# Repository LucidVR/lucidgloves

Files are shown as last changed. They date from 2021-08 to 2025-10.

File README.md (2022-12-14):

LucidGloves

# LucidGloves - Firmware and 3D Printer Files
This repo contains the arduino firmware as well as the STL files for Prototypes 3 through 4 of the LucidVR glove. This is a finger tracking glove that allows you to use your hands in VR. Follow along with Lucas_VRTech's developments on his Tiktok page:
https://www.tiktok.com/@lucas_vrtech

# Building your own gloves
**Start here at the wiki! https://github.com/LucidVR/lucidgloves/wiki**

# Support
Join the LucidVR discord server for assistance:
https://discord.gg/lucidvr

# Firmware
Open the firmware files located in the firmware/lucidgloves-firmware folder.
By default the firmware is configured for an arduino nano using serial.
To configure the firmware, change the defines in the lucidgloves-firmware.ino file.

**Configuration instructions are here: [Configuration Instructions](https://github.com/LucidVR/lucidgloves/wiki/Firmware-Setup-and-Customization-Tutorial).**\
**Firmware Troubleshooting Guide is here: [Firmware Troubleshooting Guide](https://github.com/LucidVR/lucidgloves/wiki/Firmware-Troubleshooting-Guide).** 

## Tested boards:
* Arduino Nano
* ESP-WROOM-32

## Supported Communication Methods:
* USB Serial
* Bluetooth Serial (On ESP32 boards)
* BLE (Soon, not up yet)

# Hardware
STL files for 3D printing are located in the hardware folder. 
*Prototype 4 models are currently experimental.*

The assembly **for each hand** is as follows:

For Prototypes 3 and 3.1 - 
* Spool (5x)
* Tensioner (5x)
* Cover (5x)
* Holder (5x)
* GuideRing(Will need to be resized) OR GuideNode(3.1) (2+ per finger, 1+ for thumb)
* EndCap (1x per finger, will need to be resized to fit) 

For Prototypes 4 and 4.1 - 
* HapticSpool (5x)
* Tensioner_GreenPot (5x) OR Tensioner_WLPot (5x)
* SpoolCover (5x)
* RigidMount (1x) (Left or right hand)
* WLPotSlideHolder OR WLPotElasticHolder OR GreenPotSlideHolder (5x)
* Quest2_MountSlider OR Vive3.0_MountSlider (1x)
* GuideRing (Proto 3) (Will need to be resized) OR GuideNode (Proto 3.1) (2+ per finger, 1+ for thumb)
* EndCap (Proto 3) (1x per finger, will need to be resized to fit)

Guide for printing parts: [Printing guide](https://github.com/LucidVR/lucidgloves/wiki/Parts-Printing-Guides)

**Required parts for each hand: [Parts Lists](https://github.com/LucidVR/lucidgloves/wiki/Parts-Lists)**  
Optional:  
* Joysticks for locomotion 
  - Will be making a DIY treadmill eventually as well for those who would prefer that  
* Buttons (Most can be replaced with gestures) (One is required for autocalibration)

More information will be available on the [LucidVR site](http://lucidvrtech.com/) very soon.  
*  [Prototype 3/3.1 Building Tutorial](https://youtu.be/Qj4hqRKiy8g)
*  [Prototype 4/4.1 Building Tutorial](https://youtu.be/2yF-SJcg3zQ)

# SteamVR Compatibility (OpenGloves)
This project uses the OpenGloves OpenVR driver for compatibility with SteamVR, which is downloadable on Steam:  
https://store.steampowered.com/app/1574050/OpenGloves/

Source code available on GitHub:  
https://github.com/LucidVR/opengloves-driver

# Other Languages
**[English](https://github.com/LucidVR/lucidgloves/blob/main/README.md) | [简体中文](https://github.com/LucidVR/lucidgloves/blob/main/Readme_Languages/README_CN.md)**

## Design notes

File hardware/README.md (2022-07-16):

# lucidgloves-hardware

Here are the 3D models for your printed glove parts.
The x.1 versions have slight tweaks over their counterparts to make them more easily printable and durable, so prefer those when available.
If you are on the fence between having haptics or not, you can print the Prototype v4 without servos and add them later.

Check the [printing guides](https://github.com/LucidVR/lucidgloves/wiki/Parts-Printing-Guide) to know how many you need to print and how.

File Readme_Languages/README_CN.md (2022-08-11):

LucidGloves

# lucid手套- 固件与3D打印文件
此Repo含有lucid手套的原型机V3到V4的arduino固件以及3D打印所需要的STL文件。LucidGloves是DIY触觉反馈手指追踪手套，如果配合LucidVR使用，可以在大部分支持Valve Index手柄支持的游戏。我们的宗旨是用最少的钱，得到最大的体验。原作者Lucas_VRTech会在他的抖音账号里更新此项目的最新进展, 请关注https://www.tiktok.com/@lucas_vrtech 。

# 支持此项目
欢迎计入LucidVR的discord服务器，更多详细问题以及内容可以在LucidVR的官方discord讨论:
https://discord.gg/lucidvr

# 固件
固件文件在firmware/lucidgloves-firmware文件夹.
此固件默认使用和配置arduino nano以及它的USB通讯端口。如果使用USB通讯端口，您需要使用相应的数据项与设备相连。
如果您想配置此固件，请在lucidgloves-firmware.ino文件做出相应的改变。

**详细的配置方法：请点击此处进入配置教程 -> [配置教程传送门](https://github.com/LucidVR/lucidgloves-hardware/wiki/Firmware-V2-Customization).**\
**固件问题的故障排除教程：-> [固件故障排除教程](https://github.com/LucidVR/lucidgloves/wiki/Firmware-Troubleshooting-Guide).** 

## 已测试过的主板:
	* Arduino Nano
	* ESP-WROOM-32

## 现已支持的通讯方法:
	* USB Serial
	* Bluetooth Serial (可以在 ESP32 boards实现，详情请看教程。)
	* BLE (敬请期待)

# 硬件
3D打印所需要的STL文件在hardware文件夹。
*关于原型机V4:目前还在测试阶段*

以下是针对**单个手套**需要打印以下材料：

原型机V3/V3.1：
* Spool (5x) | 卷轴
* Tensioner (5x) | 卷轴张紧器
* Cover (5x) | 卷轴保护外圈
* Holder (5x) | 卷轴固定器
* GuideRing(Will need to be resized) OR GuideNode(3.1) (2+ per finger, 1+ for thumb) | 导环
* EndCap (1x per finger, will need to be resized to fit)  | 手指套

原型机V4/V4.1：
* HapticSpool (5x) | 触觉反馈卷轴
* Tensioner_GreenPot (5x) OR Tensioner_WLPot (5x) | 触觉反馈卷轴张紧器，根据您的电位器型号选择
* SpoolCover (5x) | 卷轴保护外圈
* RigidMount (2x) (One for each hand, make sure to flip for other hand) | 固定装置
* WLPotSlideHolder OR WLPotElasticHolder OR GreenPotSlideHolder (5x) | 卷轴滑轨固定器
* Quest2_MountSlider OR Vive3.0_MountSlider (2x) | Quest2手柄固定器
* GuideRing (Proto 3) (Will need to be resized) OR GuideNode (Proto 3.1) (2+ per finger, 1+ for thumb) | 导环
* EndCap (Proto 3) (1x per finger, will need to be resized to fit) | 手指套

3D打印教程: [打印教程传送门](https://github.com/LucidVR/lucidgloves-hardware/wiki/Parts-Printing-Guides)

**需要购买的材料: [所需材料传送门](https://github.com/LucidVR/lucidgloves/wiki/Parts-Lists)**  
可选配置:  
* 遥感：可以控制人物在游戏里的运动
  - 此项目的最终计划是加入VR跑步机
* 按钮 (几乎所有按钮都可用手势替代) (至少需要一个来用作自动校准)

想要更多信息和情报？请关注[LucidVR官方网站](http://lucidvrtech.com/). 
*  [原型机V3/V3.1制作教程](https://youtu.be/Qj4hqRKiy8g)
*  原型机V4的教程会很快跟进的。

# SteamVR兼容性(OpenGloves)
此项会用到OpenVR驱动程序去兼容SteamVR, 您可以到Steam下载:  
https://store.steampowered.com/app/1574050/OpenGloves/

GitHub上已公布的源代码:  
https://github.com/LucidVR/opengloves-driver

# Other Languages
**[English](https://github.com/LucidVR/lucidgloves/blob/main/README.md) | [简体中文](https://github.com/LucidVR/lucidgloves/blob/main/Readme_Languages/README_CN.md)**

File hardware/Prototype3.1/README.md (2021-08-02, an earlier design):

# LucidGloves Hardware Prototype 3.1

See [readme.md](readme.md) for the master readme of this repository.

This folder contains the STl files for Prototype 3.1 of the LucidGloves.
Please see [Printing guide](https://github.com/LucidVR/lucidgloves-hardware/wiki/Parts-Printing-Guide) for printing instructions.

Here is a list of modified versions of Prototype 3.1:  
* Feel free to pull request a repo link to your modded version.
  - Should follow the structure of "Mod name - mod creator - link to mod"

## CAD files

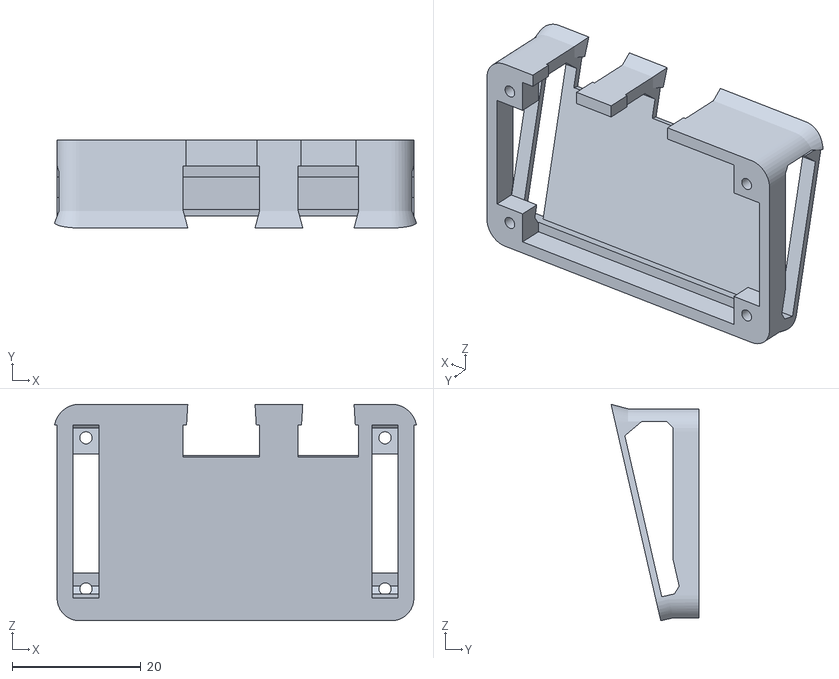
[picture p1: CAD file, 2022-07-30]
hardware/MicrocontrollerMounts/ESP32_Wroom_Holder_Desoldered_JST.STL
56.3 x 13.7 x 33.7

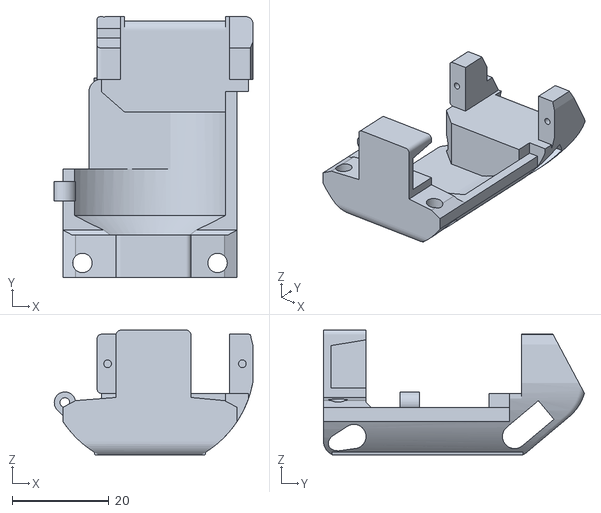
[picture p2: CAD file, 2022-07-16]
hardware/Prototype4.1/GreenPotElasticHolder_Proto4.1.STL
41.0 x 53.9 x 25.8

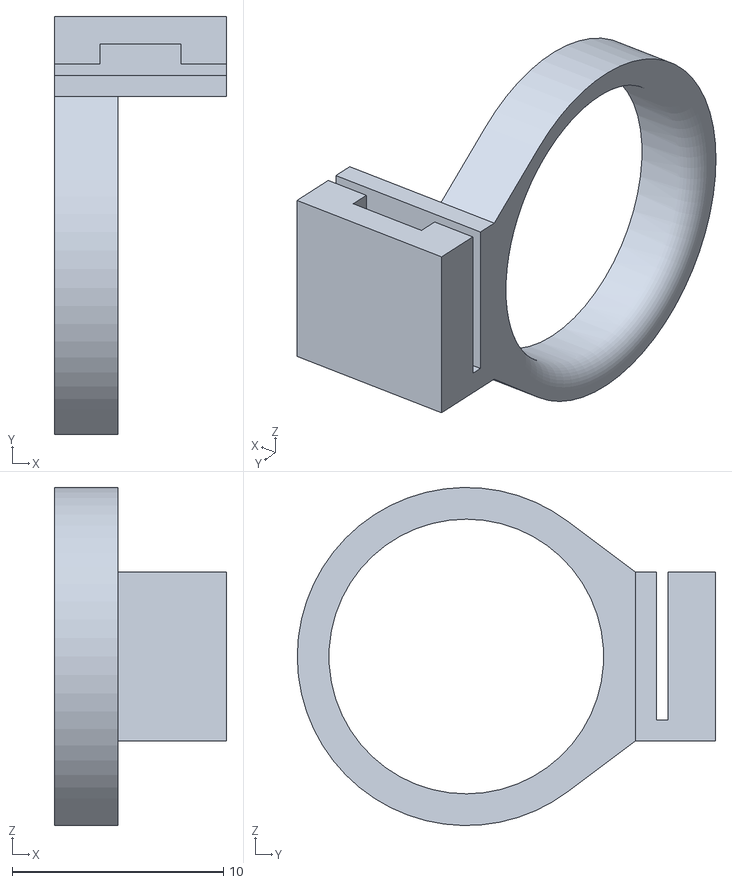
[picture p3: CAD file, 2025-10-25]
hardware/Prototype5_BETA/EndRings/EndRing_v1.2_13mm.STL
8.15 x 19.8 x 16.0

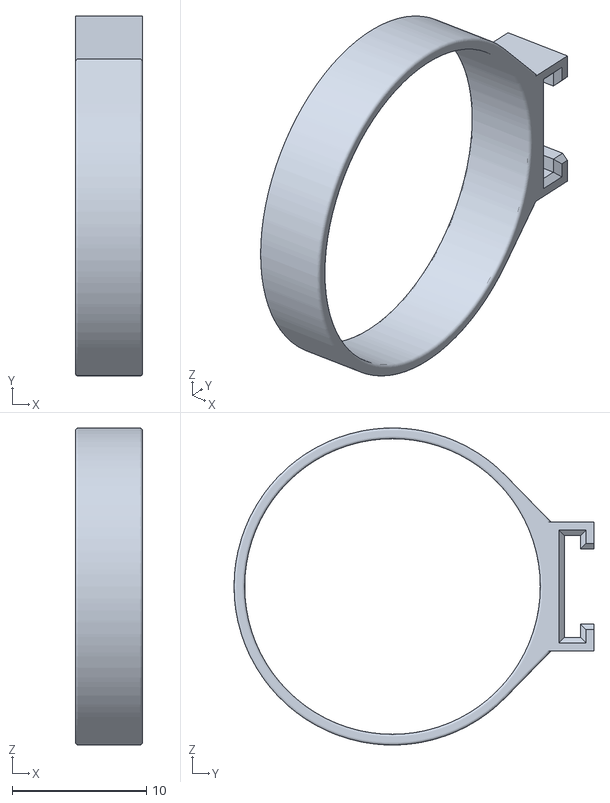
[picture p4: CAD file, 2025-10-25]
hardware/Prototype5_BETA/GuideRings/GuideRing_v1.2_22mm.STL
5.00 x 26.8 x 23.6

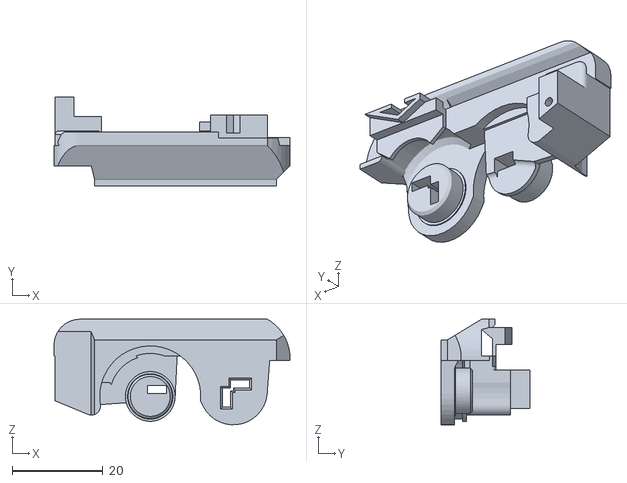
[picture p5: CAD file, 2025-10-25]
hardware/Prototype5_BETA/SensorHousing_v5.9.STL
52.1 x 19.7 x 23.3

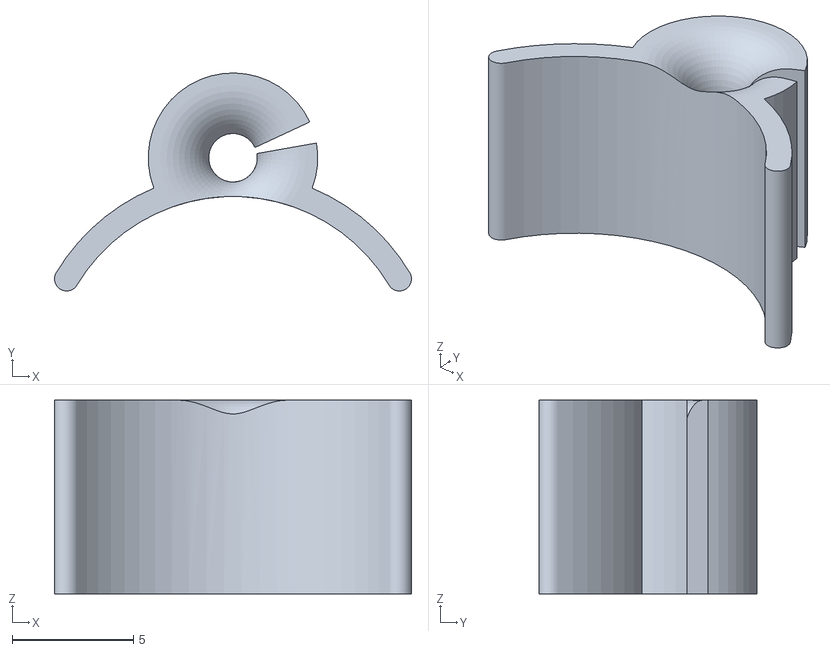
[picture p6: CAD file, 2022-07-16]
hardware/Prototype4.1/GuideNode_upgraded.STL
14.7 x 9.00 x 8.00

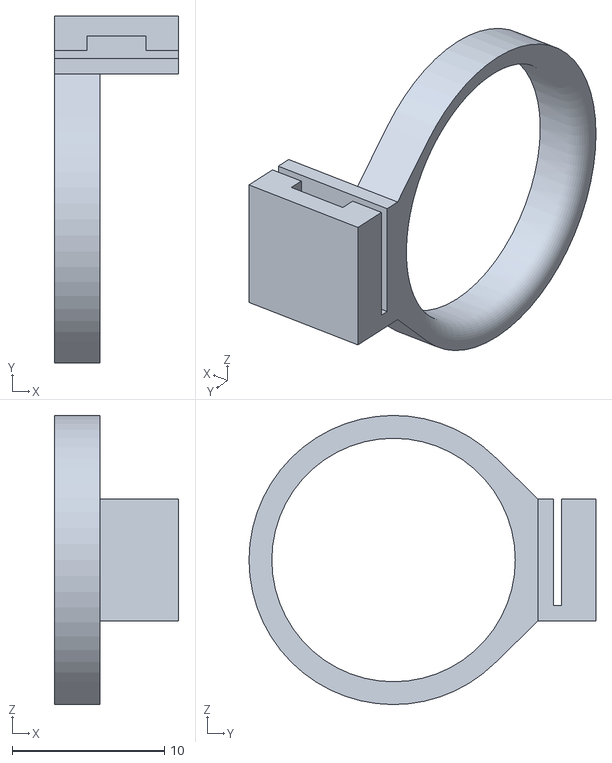
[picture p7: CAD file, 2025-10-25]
hardware/Prototype5_BETA/EndRings/EndRing_v1.2_16mm.STL
8.15 x 22.8 x 19.0

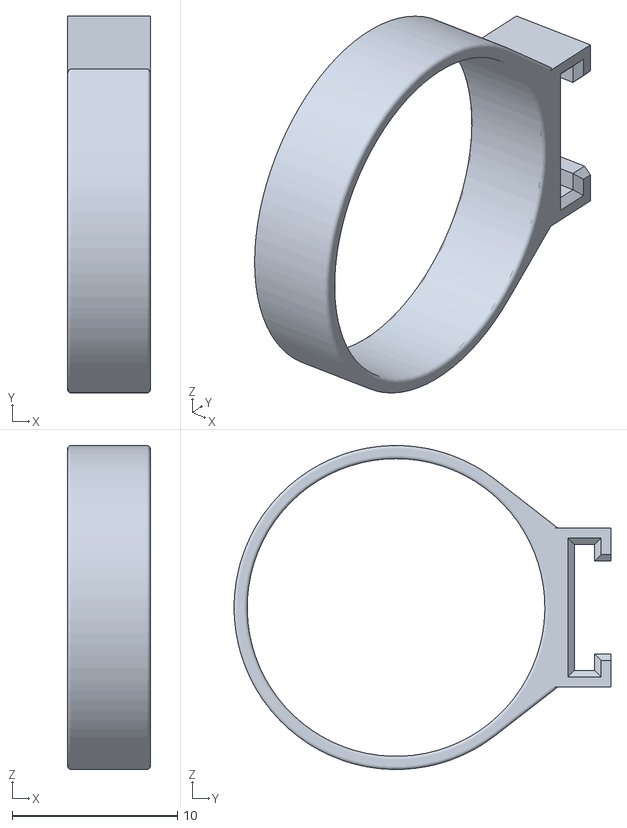
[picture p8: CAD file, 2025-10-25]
hardware/Prototype5_BETA/GuideRings/GuideRing_v1.2_18mm.STL
5.00 x 22.8 x 19.6

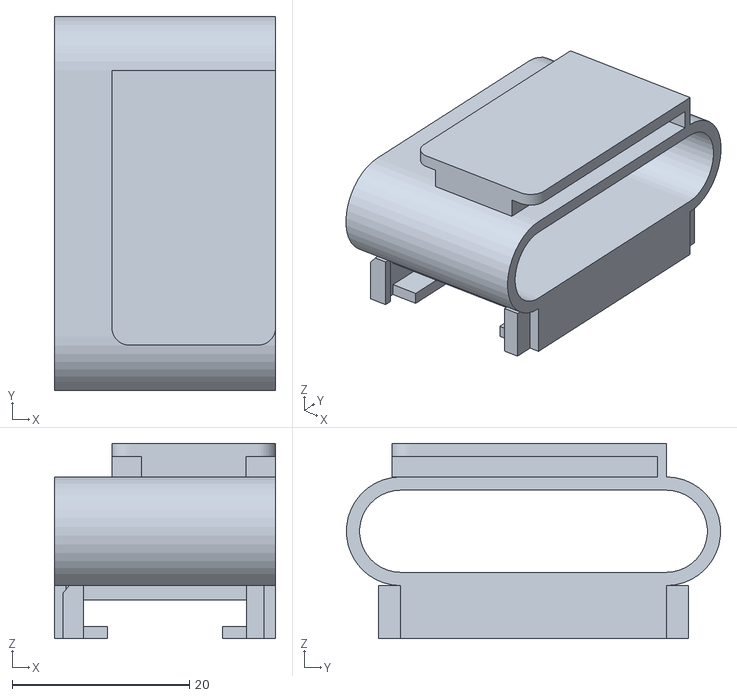
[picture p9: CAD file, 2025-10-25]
hardware/Prototype5_BETA/MountSpacer_V1.STL
25.0 x 42.2 x 22.1

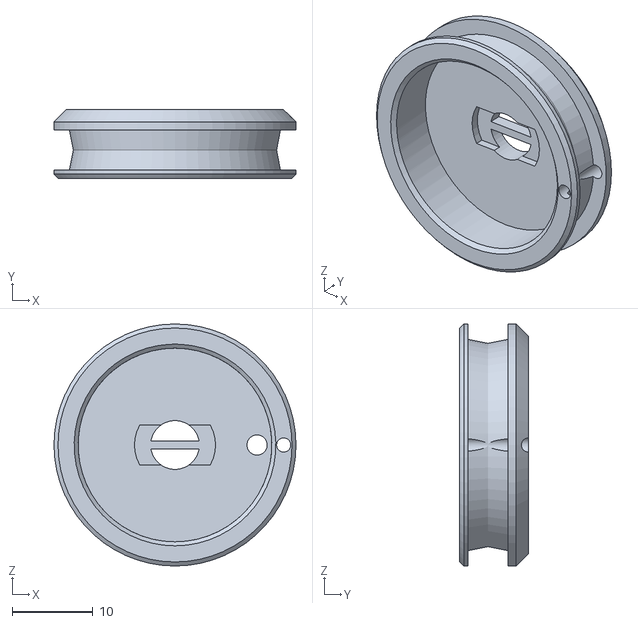
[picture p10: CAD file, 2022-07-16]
hardware/Prototype4.1/HapticSpool_Proto4.1.STL
30.0 x 8.50 x 30.0

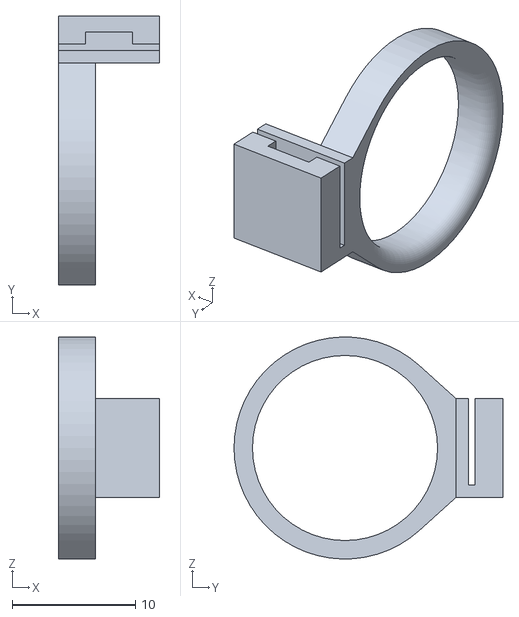
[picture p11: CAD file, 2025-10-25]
hardware/Prototype5_BETA/EndRings/EndRing_v1.2_15mm.STL
8.15 x 21.8 x 18.0

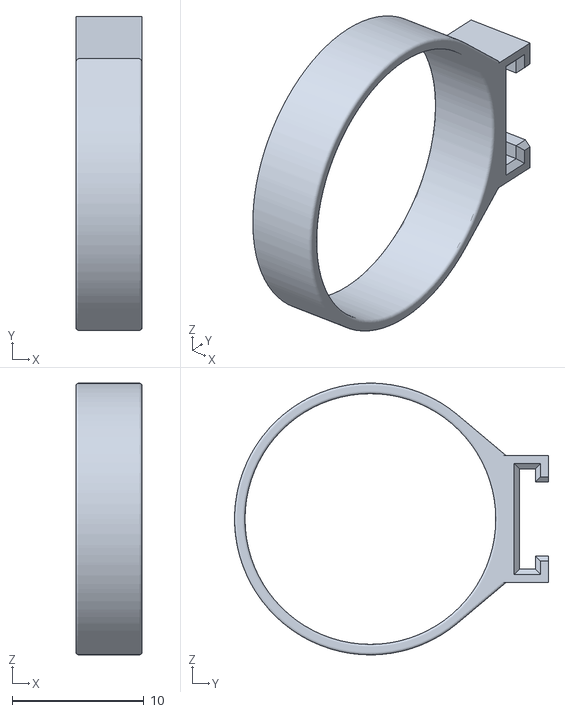
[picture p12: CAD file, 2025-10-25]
hardware/Prototype5_BETA/GuideRings/GuideRing_v1.2_19mm.STL
5.00 x 23.8 x 20.6

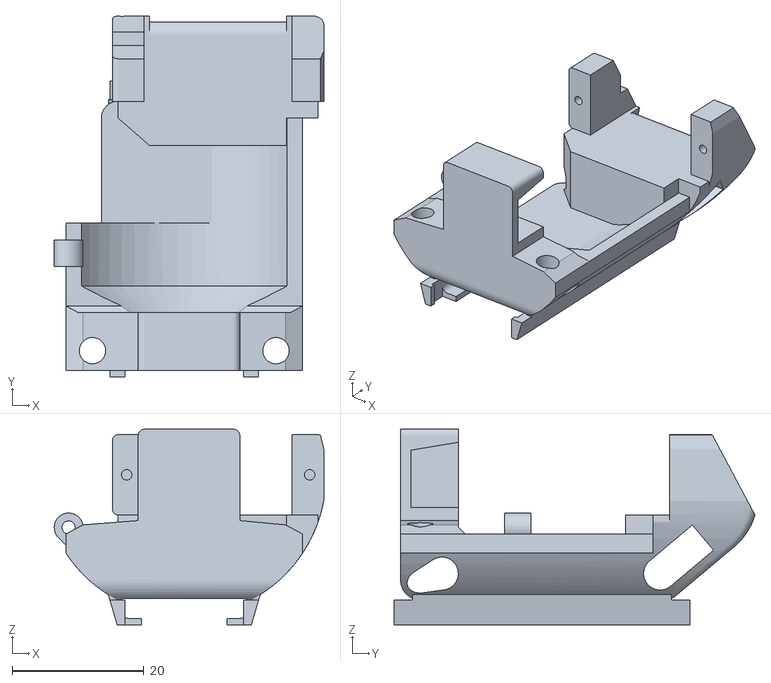
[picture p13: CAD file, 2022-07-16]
hardware/Prototype4.1/GreenPotSildeHolder_Proto4.1.STL
41.0 x 54.9 x 29.8

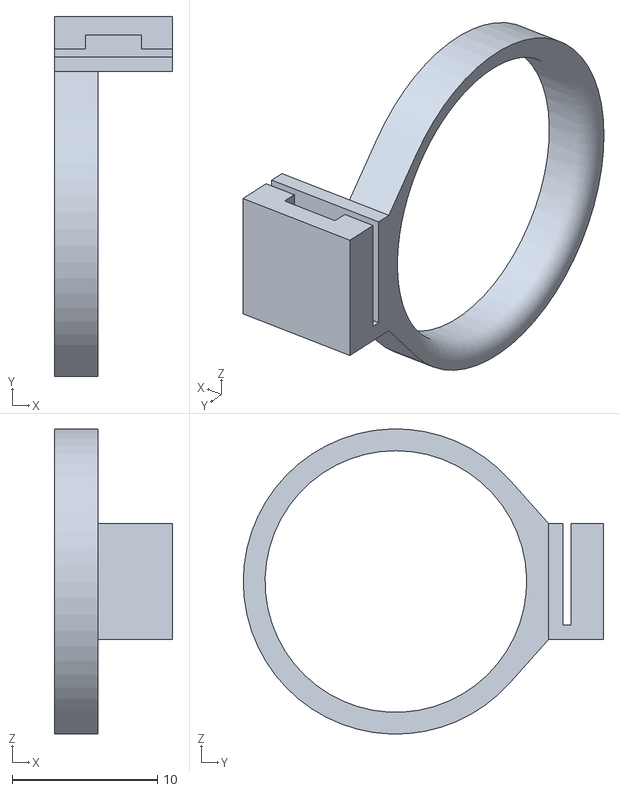
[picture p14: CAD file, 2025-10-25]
hardware/Prototype5_BETA/EndRings/EndRing_v1.2_18mm.STL
8.15 x 24.8 x 21.0

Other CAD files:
hardware/Prototype5_BETA/GuideRings/GuideRing_v1.2_17mm.STL
hardware/Prototype5_BETA/RigidMount_Splay_v4.STL
hardware/Prototype4.1/WLPotSlideHolder_Proto4.1.STL
hardware/Prototype5_BETA/GuideRings/GuideRing_v1.2_15mm.STL
hardware/Prototype3.1/Prot3.1R2_EasySpool.STL
hardware/Prototype3.1/Prot3.1R2_SpoolCover.STL
hardware/Prototype3.1/Prot3.1R2_SpoolCover_Taller.STL
hardware/Prototype3.1/Prot3.1_GuideNode.STL
hardware/Prototype3.1/Prot3.1_Holder.stl
hardware/Prototype3.1/Prot3.1_Wirecover_PublicBeta.STL
hardware/Prototype3/Prot3_Cover.STL
hardware/Prototype3/Prot3_GuideRing.STL
hardware/Prototype3/Prot3_Holder.STL
hardware/Prototype3/Prot3_Spool.STL
hardware/Prototype3/Prot3_Tensioner.STL
hardware/Prototype4.1/Vive3.0_MountSlider_v1.2.STL
hardware/Prototype4.1/WLPotElasticHolder_Proto4.1.STL
hardware/Prototype4/GreenPotElasticHolder.stl
hardware/Prototype4/GreenPotSlideHolder.STL
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

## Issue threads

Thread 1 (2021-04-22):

Assembly Guide Prototype 3

Lobotuerk, 2021-04-22:
Do you have a video or a guide to assembly prototype 3? The videos on your channel show one of the older ones, and I printed the parts for the 3.1 and have no idea how to assembly it. Thanks in advance

lucas-vrtech, 2021-04-24:
I am going to be posting a video tutorial on youtube soon.

CameronKlinge, 2021-05-02:
i need help with wiring, so I see that on the wiring demonstration it shows how to wire to the AO A1 and so on but the other 2 pins on the petameter I don't get how to wire those. btw im wiring it without a breadboard.

lucas-vrtech, 2021-05-02:
@CameronKlinge The other two pins correspond to GND and 5V. It needs to be split from the Arduino so that each potentiometer can get GND and 5V. (Or 3V3 if using an ESP32)

This guide may help:
https://www.arduino.cc/en/tutorial/potentiometer

CameronKlinge, 2021-05-02:
@lucas-vrtech Ok that makes more sense thank you so much!

danwillm, 2021-06-04:
Going to close this now that the tutorial is out, but please do feel free to re-open if you need more clarification.

Lobotuerk, 2021-06-04:
Thank you @danwillm , Awesome work

Closed 2021-06-04.

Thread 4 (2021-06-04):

Plans to support Wifi communication?

Nitwel, 2021-06-04:
Are there any plans on supporting this using websockets or something? Or are there reasons not to go this road like latency or complexity?

LittleNyanCat, 2021-11-14:
The main reason WI-FI hasn't been implemented yet is that using it on the ESP32 disables ADC2, leaving us with only 6 pins available for analog input, making tracking all fingers while having a joystick impossible without extra hardware.

You're free to implement it and contribute if you wish, but for now we don't have enough reasons to do so ourselves

minystreem, 2022-01-06:
I could try to program this, otherwise I can close this issue.

danwillm, 2022-01-06:
@minystreem
You are very welcome to implement this feature, there's been a number of people who have suggested it.

minystreem, 2022-01-06:
Ok I will start on it, I may have to make changes to Lucid-ui

danwillm, 2022-01-06:
You shouldn't have to do much on the UI, it automatically loads all the settings in `default.vrsettings` file found in the driver. Though you can add your own custom titles and descriptions to the labels and tooltips.

The majority of the work will be on the driver and firmware. Let me know if you have problems with any of that.

minystreem, 2022-01-06:
Yea I meant the driver sry. I am having trouble finding a good library

danwillm, 2022-01-06:
I recommend ASIO
https://think-async.com/Asio/

minystreem, 2022-01-06:
does that work for the esp32

danwillm, 2022-01-06:
Sorry, linked the wrong library https://github.com/zaphoyd/websocketpp (this one is the one @Nitwel was originally using but I don't think he finished his implementation)

minystreem, 2022-01-06:
So that's the library I should use for the client side AND the sever side

danwillm, 2022-01-06:
Just driver, I'm sure there's other arduino libraries for wifi.

minystreem, 2022-01-06:
Ok, I will try to find one, the WiFi library is outdated so I might have to find a different one

LittleNyanCat, 2022-01-06:
For the Esp side I've used this one for websockets in one of my projects before:
https://github.com/me-no-dev/ESPAsyncWebServer

minystreem, 2022-01-06:
Ok thx

minystreem, 2022-01-13:
@LittleNyanCat would you like to help do the driver side of things? my c++ is not very good, I got the esp side kinda working, I'm still working on it I got a bit busy. If your could help that would be nice but if not that's fine.

LittleNyanCat, 2022-01-13:
Uhh, the Arduino side stuff is also C++ though?

I'd help right now if I didn't find setting stuff up to build the driver to be such a chore

I won't be touching any driver related stuff until my gyros arrive in about a month, when that happens maybe I'll take a look at it

minystreem, 2022-01-13:
Yea building stuff is a chore for too, I'll finish the esp side

Veillax135, 2022-01-13:
Sorry, not available right now. I would if I had the time.

-Veillax135

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

CaelanTheCoder, 2022-08-16:
There's like 66 forks of this project; pretty sure at least one person has implemented WIFI communication.

minystreem, 2022-12-11:
no, I kinda abanonded it becuse I dont get the point. most forks dont have any changes

minystreem, 2022-12-11:
Wifi communicaion is hard, you try doing it

AthemiS13, 2024-12-10:
> Wifi communicaion is hard, you try doing it

Hey, have you managed to get it working? I want to do something simmilar

ElectricTurtle32, 2024-12-10:
I got the aurdino side working, but not the Pc side, I would need to dig up
the code though lol

On Tue, Dec 10, 2024, 3:44 AM Jakub Chmelař ***@***.***>
wrote:

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

AthemiS13, 2024-12-10:
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

Could you send me your discord or something please so i can contact you privately?

ElectricTurtle32, 2024-12-16:
I don't think I have the code anymore unfortunately, I am very sorry. I
wish you luck on your project though!

On Tue, Dec 10, 2024 at 8:31 AM Jakub Chmelař ***@***.***>
wrote:

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

JohnRThomas, 2024-12-23:
@AthemiS13 The driver needs to be modified, but this is the start of serial over wifi that you can rip from my fork if you want to try it: https://github.com/JohnRThomas/OpenGloves-Firmware/blob/main/open-gloves/SerialWIFICommunication.hpp

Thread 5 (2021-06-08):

Suggestions for the 3D models.

Nitwel, 2021-06-08:
I'm currently printing the parts for the glove and noticed some minor problems with the 3d models that could be improved upon.

1. The tensioner has this small corner arround it which my prusa mini couldn't handle even on 0.10mm layer height so the casing wouldn't hold. I added a bigger corner to hold on to which was much easier to print even on 0.25mm layer height. So if you'd like you could add this to the tensioner.
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

2. The overhang on the spool hoder could cause trouble when printing so adding a soother edge here could improve the prints:
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

Other than that the 3D Models are really well designed and I'm really excited to test the glove out!
Thank you so much for comming up with this idea and making it a reality. ❤️

lucas-vrtech, 2021-06-19:
Yeah, I have some printability improvements coming up in prototype 4 soon. I'll make some changes to the snap ridge you mentioned, but unfortunately adding a chamfer to the spool like in your second image may be problematic as in my testing it sometimes guides the string off of the spool requiring you to take it apart and fix

Closed 2021-06-19.

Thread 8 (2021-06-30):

No home button mapping in firmware

Watermelon4man, 2021-06-30:
Add a home button define pin in the firmware as it is missing.

lucas-vrtech, 2021-06-30:
Good idea, I can add that in. It is also missing from the driver so I'll have to add it there as well.

lucas-vrtech, 2021-08-03:
I've added a menu button to the firmware and driver. Will be released with OpenGloves driver v0.4 :)

Closed 2021-08-03.

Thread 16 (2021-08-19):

Add documentation for adding required ESP32 libraries

lucas-vrtech, 2021-08-19:
This is a pretty quick first issue if someone wants to take it,
Currently in order to use the firmware with ESP32, one needs to get the ESP32 libraries from the Arduino IDE package manager,
And in order to use the servos for force feedback, one needs to get the ESP32servo library

Closed 2021-09-01.

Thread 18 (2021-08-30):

OBJ or  similar file type for the 3d parts?

MJ26gaming, 2021-08-30:
The STLs work fine for 3d printing, but having OBJs or STEPs for them so that way we can edit and customize them in CAD software would be nice

Bossbam, 2021-09-02:
I know it's not the best solution, but if you just download blender you can really quickly import the file as an STL and then export it as an OBJ

lucas-vrtech, 2021-09-04:
Currently, I am not releasing the step files for the entire glove itself, but will be probably releasing step files for the modular controller mount system soon. This may change in the future.

Closed 2021-09-04.

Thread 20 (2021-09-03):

Inseam on spool too small

Rat-Boi-Bop, 2021-09-03:
I am a dumb person and would like help. The inseam on the spool stl file isn't showing up on the layer view, apparently it is so small my printer can't see it and so it just skips it. You can see how this is an issue. Please advise.

Zach710032, 2021-09-03:
same probelm as above^ adding z layer fixed it.

lucas-vrtech, 2021-09-04:
I will be throwing up some new STL files with release proto 4.0.1 which will fix this issue. Thank you for pointing it out. This is actually a problem carried from the original prototype 3 that was fixed in 3.1. For some reason the fix did not carry over to prototype 4 so I will do that manually.

wpuchalski, 2021-09-07:
I have the exact same issue I thought it was something I was doing with my printer. Glad to hear I'm not the only one. Thanks for all your work Lucas.

wpuchalski, 2021-09-10:
Just as a heads up I modeled up a new spool and am printing it now, if it works I could share the file with you Rat-Boi-Bop and Zach

lucas-vrtech, 2021-11-21:
Solved in prototype 4.1

Closed 2021-11-21.

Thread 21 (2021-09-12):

ValueError: could not convert string to float: '511&511&511&511&511&232&164&0&0&0&0&0&0'

ruchitsheth, 2021-09-12:
I am using the Prototype 1 Code for blender and when I am trying to run the code with a potentiometer as input, I am getting the following error

Read blend: C:\Users\Ruchit\Downloads\lucidgloves-blender-main\lucidgloves-blender-main\VRGloveDemo_Attempt2.blend
b'511&511&511&511&511&232&164&0&0&0&0&0&0\n'
Traceback (most recent call last):
  File "C:\Users\Ruchit\Downloads\lucidgloves-blender-main\lucidgloves-blender-main\VRGloveDemo_Attempt2.blend\script.py", line 43, in <module>
ValueError: could not convert string to float: '511&511&511&511&511&232&164&0&0&0&0&0&0'
Error: Python script failed, check the message in the system console

Please help ME!

lucas-vrtech, 2021-09-25:
This isn't a problem with lucidgloves firmware, rather it's something that needs to be fixed in the blender script. I'll leave this issue open to make sure I/someone fix it at some point.

fionn77, 2021-12-29:
in blender change this line :
lineTable = read.decode().split(',')           to
lineTable = read.decode().split('&')

fionn77, 2021-12-29:
use new lucidgloves-firmware and use this code in main instead of original:

#define ALWAYS_CALIBRATING CALIBRATION_LOOPS == -1

String CommandFromPC;
static char stringToPrint[75];

ICommunication* comm;
int loops = 0;

void setup() {
  // Command string for serial interface
  CommandFromPC = "";

  #if COMMUNICATION == COMM_SERIAL
    comm = new SerialCommunication();
  #elif COMMUNICATION == COMM_BTSERIAL
    comm = new BTSerialCommunication();
  #endif
  comm->start();

  setupInputs();

}

void loop() {
//  if (comm->isOpen()){
    #if USING_CALIB_PIN
    bool calibButton = getButton(PIN_CALIB);
    if (calibButton)
      loops = 0;
    #else
    bool calibButton = false;
    #endif

    bool calibrate = false;
    if (loops < CALIBRATION_LOOPS || ALWAYS_CALIBRATING){
      calibrate = true;
      loops++;
    }

    int* fingerPos = getFingerPositions(calibrate, calibButton);
//    int* fingerPos;

    bool joyButton = getButton(PIN_JOY_BTN);

    #if TRIGGER_GESTURE
    bool triggerButton = triggerGesture(fingerPos);
    #else
    bool triggerButton = getButton(PIN_TRIG_BTN);
    #endif

    bool aButton = getButton(PIN_A_BTN);
    bool bButton = getButton(PIN_B_BTN);

    #if GRAB_GESTURE
    bool grabButton = grabGesture(fingerPos);
    #else
    bool grabButton = getButton(PIN_GRAB_BTN);
    #endif

    #if PINCH_GESTURE
    bool pinchButton = grabGesture(fingerPos);
    #else
    bool pinchButton = getButton(PIN_PNCH_BTN);
    #endif

    //  OUTPUT
    //    comm->output(encode(fingerPos, getJoyX(), getJoyY(), joyButton, triggerButton, aButton, bButton, grabButton, pinchButton));

    CommandFromPC = Serial.readStringUntil('\n');
    if(CommandFromPC == "Hello Arduino") {
      Serial.println("What is your Bidding my Master");
    } else if (CommandFromPC == "READ_VALUES") {
//       Serial.println( encode(fingerPos, getJoyX(), getJoyY(), joyButton, triggerButton, aButton, bButton, grabButton, pinchButton) );

//         fingerPos = getFingerPositions(calibrate, calibButton);

         sprintf(stringToPrint, "%d&%d&%d&%d&%d\n",  fingerPos[4], fingerPos[3], fingerPos[2], fingerPos[1], fingerPos[0]  );

//         Serial.println(stringToPrint);
         Serial.print(stringToPrint);
         Serial.flush();

    }

    delay(LOOP_TIME);
//  }
}

after that you can delete Encoding tab

CaelanTheCoder, 2022-08-16:
this issue is outdated right?

CaelanTheCoder, 2022-08-16:
this can safely be closed right?

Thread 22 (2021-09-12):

ESP32s not sending/recieving

JamesPCVR, 2021-09-12:
I have uploaded the software to both gloves and have connected them to my computer over Bluetooth. The opengloves driver is able to track their position but I have no button inputs, finger tracking or haptic feedback. I am able to perform auto-calibration in the driver but not extend/retract the servos fully, I'm just told the command could not be added to the pipeline.

The configuration in the opengloves driver is as follows:
Both gloves enabled
Communication method Bluetooth serial
Right name: lucidgloves-right (same for firmware and serial number)
Left name: lucidgloves-left (same for firmware and serial number)
Driver emulation: lucid glove
Encoding protocol: Alpha

Any fixes?

lucas-vrtech, 2021-09-25:
Are you able to check the bluetooth output in arduino IDE over bluetooth serial port numbers?

Zach710032, 2021-09-26:
Change your comms method to usb serial and use the serial monitor(in arduino ide go to tools>serial monitor and then change baud rate to 115200) to see if your pots are actually sending positional data to the Esp32s and then to the computer. then, make sure you have the comms method changed back to btserial when you have verified the positional tracking works. Make sure opengloves is enabled in steam, and try flipping your pot values if you think you may have wired them backwards.

danwillm, 2021-09-27:
In addition to this, SteamVR must be open for those functions to work. In a later release, this won't be needed.

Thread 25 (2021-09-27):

Latency issue and loss of connection when using bluetooth

jschung1111, 2021-09-27:
After building my pair of gloves, I tried testing each of the gloves that I've made. The right glove worked wonderfully. However, when I went to check my left glove, I noticed significant latency issues and after a few seconds it would disconnect and I would have to restart Steam VR to get it to connect again (only to have it repeat the issue that I just mentioned). Any ideas on what's causing this issue?

danwillm, 2021-09-27:
Interesting, does this happen with both gloves when they're connected?

There's a couple of bluetooth fixes that may or may not be related to the issue you are having on the beta branch on Steam, could you try opting into it and see if that helps things (you can opt into the beta by right clicking opengloves in the Steam library list->properties->betas and select the beta branch.

Let me know if that fixes things.

Thanks.

lucas-vrtech, 2021-11-21:
Closing this issue now, but feel free to reopen if needed or ask around in the discord. Biggest recommendation I can give is to try out ESP32-WROOM-32U's with an external antenna as it helps with signal strength significantly

Closed 2021-11-21.

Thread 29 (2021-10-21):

Individual analog max values

ArielWolle, 2021-10-21:
Hey is there any plan to have an individual analog max value, my gloves grip gesture never works as the analog max is never reached on many of the fingers while one is an outlier, having individual analog max would fix this issue.

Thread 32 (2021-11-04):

Code more buttons

Reru01, 2021-11-04:
Hey, could you add code that allows for adding more buttons? I want to have 9 buttons on my device because I run out of buttons on my index controller that has 3, so adding the ability for people to add more buttons to the gloves natively allows for even better and more customized DIY gloves... I have another friend that wants to add like 12+ buttons to a glove if they ever make them.

danwillm, 2021-11-11:
This isn't something that we're looking to implement in the near future, though it is certainly possible to extend both the driver and firmware to allow for this. There is some difficulty in getting hand tracking to work along with non-index controllers (some games don't enable finger tracking unless there are index controllers present, though there are ways around this), but if you do decide to fork off your own firmware and driver to allow for more buttons than feel free to reach out and we can help with those problems.

Closed 2021-11-21.

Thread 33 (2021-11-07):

My Hands are not responding to the finger movements in SteamVR home

hlaila1, 2021-11-07:
Hi There,

So I followed all the steps and installed all the drivers required. I've downloaded the latest Driver 0.4 release and changed the values to 1023 because I am using Nano. Also in the Driver settings I made sure the COM ports are the same as my Arduino.

The "Serial Monitor" showed big and small numbers meaning it is working as Lucas has showed in the video. After I linked my Oculus Rift S, and launched SteamVR. It showed the Valve Controllers following my Oculus Controllers. When I am at "Steam HOME" My hands appears but they are not responding to the finger movements and also they are showing only 3 fingers and a Thumb!!

I am not sure what if I am missing something here, Please help :(

danwillm, 2021-11-07:
The three fingered hand in SteamVR Home is an intenional hand model made by the SteamVR developers, and does not respond to finger movement. In the SteamVR Home menu, change your hand model to the five fingered hand (by pressing the b button on the controller. You might need to deactivate the openglove driver first to use your primary controllers, either in SteamVR settings or in the openglove configuration file)

Did you download the driver on Steam? If you change the hand model to a five fingered hand and it does not respond to finger movement, please delete whatever you installed previously. There is a configuration ui in the steam release that makes it easier to configure settings.

hlaila1, 2021-11-08:
Thank you @danwillm appreciate helping me with this awesome project.
so I figured our how to change the hand styles. Now I still have the same issue of the fingers are not responding to the movement and it is just a fronzen hand floating and following the movement of my oculus controller.
I am not sure what is the problem, all the ports and the configurations are correct. :( :(
I've attached few picture of the glove. Please see below

I meant to ask you, and please feel free to say no, but I would like to schedule a call with you to go over the glove build if you don't mind of course. Also I would like to discuss with you and Lucas how can help you guys and support this project, please let me know.

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
.

danwillm, 2021-11-08:
Please make sure that you have installed the driver on steam, instead of downloading it via GitHub - it'll make life a lot easier for you with a ui for managing configuration options, and automatically installing the driver. If you do this, please make sure to remove whatever files you added to SteamVR previously for opengloves. Clicking launch after donwloading it on Steam will present a configuration interface to you where you can alter these settings.

If it's still causing you problems, feel free to attach the vrserver log files here and I can take a further look. `C:\Program Files (x86)\Steam\logs\vrserver.txt`

Lucas and I are pretty tight for time at the moment, so it might be hard to find a time that works, but feel free to send a message on the discord server, or a dm to either of us there. `danwillm#8254`

danwillm, 2021-12-28:
As we haven't heard back, I'm going to close this due to inactivity and I'm assuming this issue has been fixed.

If it hasn't, feel free to attach your log files either here or on discord, and we can reopen the issue.

Closed 2021-12-28.

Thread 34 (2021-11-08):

Spool cover and tensioner not connecting

AbsoluteXero132, 2021-11-08:
I printed the tensioner and spool cover pieces and they are not connecting properly. In the video he was able to put them on without issue. I was able to get them together, but they broke in the process. They were printed with a resin printer. Is that the problem? I tried using a 3D printer but it was having issues.

jlschaper, 2021-11-20:
I haven't printed the parts in resin (but was thinking of giving that a go) but make sure you've sanded any elephant footing etc off.  Also consider volumetric shrinkage when curing - can be up to 5 or 6%!!  If I can find time I might print a v4 set in resin and see how it goes too.

lucas-vrtech, 2021-11-21:
Another think to keep in mind (and I'm not sure how this translates to SLA printers, but) you want to make sure that you keep print the cover with the side that has a lip AWAY from the bed, because that's the part that is the most sensitive to elephant's foot.

DirtyBong, 2022-01-12:
I'm having the same issue, on the previous prototype they snapped in for me but for this print I've only gotten 1 out of 10 to snap-in. It might just be of my own doing but I'm not sure what would be causing it. I even printed them with the lip away from the bed as Lucas suggested and still didn't seem to help much.

jlschaper, 2022-01-14:
I found that if I clipped the ring on the tensioner *before* curing there wasn't the issue of snapping.  It requires a little more fiddling around to get the spring hook in, but once you start winding there was no difference.
If that isn't feasible, maybe take a sharp knife/scalpel and cut a notch in the lip of the tensioner and in the lip of the ring and then "screw"/twist the cover on rather than snapping it on.

Closed 2022-07-12.

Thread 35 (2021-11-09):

Arduino IMU Tracking?

QueasyQolon, 2021-11-09:
Would it be feasible to add Arduino-based tracking with a gyroscope/accelerometer sensor? That would allow for tracking that doesn't require existing VR controllers / trackers, since Vive tracker pucks are kinda pricey.

StephenIndustries, 2021-11-09:
Unfortunately, IMU tracking is both beyond the scope of this project, and wouldn't be nearly reliable enough to be a viable tracking method. As it stands, IMUs have too much inherent drift to viable in and of themselves as a tracking method.

LittleNyanCat, 2021-11-14:
This has been asked many times in our discord server and short answer is no. Even SlimeVR will most likely to be too innacurate/drifty for something that requires precision like your hands

lucas-vrtech, 2021-11-21:
Closing for the same reason LittleNyanCat mentioned. IMU based tracking could be used for wrist tracking, which would allow you to place your controller/tracker further up the arm, but that's about it unfortunately, until there's a really good DIY solution to counter IMU drift. Hopefully the SlimeVR guys can get it more accurate someday that we can work together on some cool hand tracking solution.

Closed 2021-11-21.

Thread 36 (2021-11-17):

OpenVR Init Error

NoavanBentem, 2021-11-17:
Using a Esp32 devkit v1 and following all steps closely it seems something isn't going as planned. Very unsure where the problem might be as I'm not yet so advanced in electronics(but getting better). What catched my eye is my serial output looks way different from what yours showed in one of your videos("How I build CHEAP VR Gloves.")

Mine looks more like this:
A1662B3329C1229D4095E4095F384G0ILM
A112B3994C305D4095E1017F336G34ILM
A2816B4037C3596D4095E1115F469G56ILM
A852B3344C240D4095E4095F349G0ILM

Just to be sure I tried a nano as well with same serial output

LittleNyanCat, 2021-11-17:
That video is relatively old and using what we now call the "legacy" encoding. You are using the alphanumeric encoding which is the current encoding we use

danwillm, 2021-12-28:
I'm going to close this due to inactivity. Like @LittleNyanCat mentioned, you should be using alpha encoding.

If you're running into issues that relate to your title "OpenVR Init Error" (or are on the pc side of things), that is something different to this, and you should open an issue on the [opengloves](https://github.com/LucidVR/opengloves-driver) repo.

Closed 2021-12-28.

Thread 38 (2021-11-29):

Unable to load configuration, please open an issue on GitHub: OpenVR Init Error

SB2203, 2021-11-29:
Hello everyone :)
Loading the firmware on the ESP32 worked as planned, but as soon as I started "open gloves" on steam, I got the error message written in the title. Serial and BT connection both result in the same error.

LittleNyanCat, 2021-11-29:
Just to check, you got SteamVR installed and running, yes?

SB2203, 2021-11-29:
yes it is running

danwillm, 2021-11-29:
You'll also need to make sure that you have a headset connected. Do you have one connected?

SB2203, 2021-11-29:
Awesome, thank you very much! I did not know I needed to connect a headset.

danwillm, 2021-11-29:
Great, no problem. Going to close this now but feel free to reach out if you have any other problems.

Closed 2021-11-29.

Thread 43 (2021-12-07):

[Idea] Linear potentiometers

Hexality, 2021-12-07:
My idea was to make this work using linear potentiometers
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
(example)
instead of regular ones with a push-back motor attached to make it less bulky.

do you think that would work?

LittleNyanCat, 2021-12-07:
Yes, it's been discussed quite extensively in our discord server, they work without any software changes needed

Hexality, 2021-12-07:
nice, thank you.

Closed 2021-12-07.

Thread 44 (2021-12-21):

Error compiling for board ESP32 Wrover Module.

slobershelf, 2021-12-21:
when I try to download the program after following the steps it says   input[size] = NULL;
                   ^
At global scope:
cc1plus.exe: warning: unrecognized command line option '-Wno-frame-address'
c:/users/       /appdata/local/arduino15/packages/esp32/tools/xtensa-esp32-elf-gcc/1.22.0-97-gc752ad5-5.2.0/bin/../lib/gcc/xtensa-esp32-elf/5.2.0/../../../../xtensa-esp32-elf/bin/ld.exe: cannot find crt1-sim.o: No such file or directory
c:/users/         /appdata/local/arduino15/packages/esp32/tools/xtensa-esp32-elf-gcc/1.22.0-97-gc752ad5-5.2.0/bin/../lib/gcc/xtensa-esp32-elf/5.2.0/../../../../xtensa-esp32-elf/bin/ld.exe: cannot find _vectors.o: No such file or directory
collect2.exe: error: ld returned 1 exit status
exit status 1
Error compiling for board ESP32 Wrover Module.

LittleNyanCat, 2021-12-21:
Oh great, it's that annoying bug that we have no idea why it happens and not our fault again.

Anyhoo, the fix is uninstalling the IDE, nuking the Arduino15 folder in Appdata/Local and reinstalling everything again

slobershelf, 2021-12-21:
Thank u lol it’s been happening all day--
Nicholas Leite

slobershelf, 2021-12-21:
question how do you uninstalling the IDE and all that

slobershelf, 2021-12-21:
question how do you uninstalling the IDE and all that

LittleNyanCat, 2021-12-21:
Google how to uninstall programs, it's not that hard.

To delete the Arduino15 folder navigate to C:\Users\<username>\AppData\Local

slobershelf, 2021-12-21:
thank u <3

Closed 2021-12-21.

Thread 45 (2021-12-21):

A fatal error occurred: Failed to connect to ESP32: Timed out waiting for packet header

slobershelf, 2021-12-21:
esptool.py v3.0-dev
Serial port COM3
Connecting........_____....._____....._____....._____....._____....._____.....____An error occurred while uploading the sketch
_

A fatal error occurred: Failed to connect to ESP32: Timed out waiting for packet header

LittleNyanCat, 2021-12-21:
Press and hold the BOOT/IOO (whichever your board has) as soon as you press the upload button. Release when it says the upload is done. That should do it

slobershelf, 2021-12-21:
it got closer but it said
esptool.py v3.0-dev
Serial port COM3
Connecting....
Chip is ESP32-D0WDQ6 (revision 1)
Features: WiFi, BT, Dual Core, 240MHz, VRef calibration in efuse, Coding Scheme None
Crystal is 40MHz
MAC: 84:cc:a8:3f:6c:38
Uploading stub...
Running stub...
Stub running...
Changing baud rate to 921600
Changed.
Configuring flash size...
Warning: Could not auto-detect Flash size (FlashID=0x0, SizeID=0x0), defaulting to 4MB
Compressed 8192 bytes to 47...
Writing at 0x0000e000... (100 %)
Wrote 8192 bytes (47 compressed) at 0x0000e000 in 0.0 seconds (effective 5461.4 kbit/s)...

A fatal error occurred: Timed out waiting for packet header
A fatal error occurred: Timed out waiting for packet header

slobershelf, 2021-12-21:
it got closer but it said

esptool.py v3.0-dev
Serial port COM3
Connecting....
Chip is ESP32-D0WDQ6 (revision 1)
Features: WiFi, BT, Dual Core, 240MHz, VRef calibration in efuse, Coding Scheme None
Crystal is 40MHz
MAC: 84:cc:a8:3f:6c:38
Uploading stub...
Running stub...
Stub running...
Changing baud rate to 921600
Changed.
Configuring flash size...
Warning: Could not auto-detect Flash size (FlashID=0x0, SizeID=0x0), defaulting to 4MB
Compressed 8192 bytes to 47...
Writing at 0x0000e000... (100 %)
Wrote 8192 bytes (47 compressed) at 0x0000e000 in 0.0 seconds (effective 5461.4 kbit/s)...

A fatal error occurred: Timed out waiting for packet header
A fatal error occurred: Timed out waiting for packet header

StephenIndustries, 2021-12-21:
Can you try **holding**  the button down until it finishes uploading?

slobershelf, 2021-12-21:
I did

slobershelf, 2021-12-21:
it did the same thing

LittleNyanCat, 2021-12-21:
What board do you have set in the IDE?

slobershelf, 2021-12-21:
where do you check

LittleNyanCat, 2021-12-21:
It's under tools

slobershelf, 2021-12-21:
ESP32 Dev module

LittleNyanCat, 2021-12-21:
Try switching that to Node32s

slobershelf, 2021-12-22:
same error

Sketch uses 949498 bytes (72%) of program storage space. Maximum is 1310720 bytes.
Global variables use 31172 bytes (9%) of dynamic memory, leaving 296508 bytes for local variables. Maximum is 327680 bytes.
esptool.py v3.0-dev
Serial port COM3
Connecting....
Chip is ESP32-D0WDQ6 (revision 1)
Features: WiFi, BT, Dual Core, 240MHz, VRef calibration in efuse, Coding Scheme None
Crystal is 40MHz
MAC: 84:cc:a8:3f:6c:38
Uploading stub...
Running stub...
Stub running...
Changing baud rate to 921600
Changed.
Configuring flash size...
Warning: Could not auto-detect Flash size (FlashID=0x0, SizeID=0x0), defaulting to 4MB
Compressed 8192 bytes to 47...
Writing at 0x0000e000... (100 %)
Wrote 8192 bytes (47 compressed) at 0x0000e000 in 0.0 seconds (effective 5957.9 kbit/s)...

A fatal error occurred: Timed out waiting for packet header
A fatal error occurred: Timed out waiting for packet header

Benjamin5678, 2022-01-18:
Have you downloaded these drivers? Its 4th in list https://www.silabs.com/developers/usb-to-uart-bridge-vcp-drivers

danwillm, 2022-03-06:
I'm assuming this issue is fixed. I'll close this issue now, but feel free to reopen if you're still running into problems.

Closed 2022-03-06.

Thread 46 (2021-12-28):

potentionometer wont work?

Philliboyxd, 2021-12-28:
hi guys i finished my left glove by using all the thinks lucas has. i wired everything to the esp32 wroom-32 v1 mpdul and when i go to the serial port und move my thumb and pint finger the numbers change but when i move my pinky or middle finger the numbers are all the same :( Pls help me and i wired everthing to the pins and change it in the ide to the pins that i use

LittleNyanCat, 2021-12-28:
What pins did you use? Some pins don't have ADCs and thus can't be used for the pots

Philliboyxd, 2021-12-28:
i used g34,g35,g32,g25,g26

LittleNyanCat, 2021-12-28:
Alright, all of those have ADCs. Double check your wiring then, that's always the problem everyone tends to have. Just because it looks good doesn't mean it is good

Philliboyxd, 2021-12-28:
ok i checkt all of it and all are conecctect perfect to the potetinomiter as well to the dev board
can there be any other problem?

LittleNyanCat, 2021-12-28:
How did you "checkt" it?

Philliboyxd, 2021-12-28:
i pull the wire and look at this if its connected to the board and potentionometer. is it wrong?

LittleNyanCat, 2021-12-28:
Check if there is an actual proper connection with a multimeter

Philliboyxd, 2021-12-28:
multimeter?

LittleNyanCat, 2021-12-28:
Yes. Multimeters are an essential tool when doing anything electronics related

Philliboyxd, 2021-12-28:
ah that the wires are not broken ?

Philliboyxd, 2021-12-28:
what problem culd be there anyways `?

Closed 2021-12-28.

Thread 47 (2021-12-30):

ESP32 wont sent to my computer

Philliboyxd, 2021-12-30:
i connected everything right and installed the firmware on the esp32 with BTSerial bevor i did that i connected it with only serial port to check if its connecting to the pc everthing perfect aslong i dont use BTSerial anyone could help me? :(

danwillm, 2021-12-30:
If you could provide some info on what exactly the problem was, I'm sure others who might have run into the same issue would find it helpful.

Closed 2021-12-30.

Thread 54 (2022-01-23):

Potentiometers are too high friction, don't retract quickly

The15thGamer, 2022-01-23:
Building the spools, the potentiometers used are the same WL Brass potentiometers as listed in the wiki, linked here: https://www.amazon.com/gp/product/B07VQTFFGC
Also using the same badge reel springs as directed. But the spool retracts very slowly, and the potentiometers seem to be really high friction and are causing this lag.

LittleNyanCat, 2022-01-23:
Common issue, check the FAQ in our discord server

The15thGamer, 2022-01-23:
> Common issue, check the FAQ in our discord server

Than you! Will do.

Closed 2022-01-23.

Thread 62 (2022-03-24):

No download link for 4.0 RigidMount_rightHand.stl

aakoch, 2022-03-24:
Something's goofy about RigidMount_rightHand.stl. There's no download link like there is for the left hand. I can view the raw blob,  but not sure it would download correctly. I guess I can always try. Anyway, just a heads up.

danwillm, 2022-03-24:
This is a problem with GitHub. It is recommened to download the entire repo (either with git or using the green download button to download as zip) to get the parts, instead of downloading them individually.

Closed 2022-03-24.

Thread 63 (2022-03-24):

v4 STL Dimensions?

aakoch, 2022-03-24:
Something is off. It might be me, I admit. But when I put the STLs in 2 different programs, it doesn't look like the dimensions would work. When I laid out the green pot sliders with the rigid mount, the sliders would occupy the same space:
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

And they look too long:
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

But where they actually slide together (height and width) looks correct.

Am I crazy?

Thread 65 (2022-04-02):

Can't upload to development board

GZXH123, 2022-04-02:
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

LittleNyanCat, 2022-04-02:
You must install the ESP32 as a devboard on your Arduino IDE. Follow the [firmware setup guide](https://github.com/LucidVR/lucidgloves/wiki/Firmware-Setup-and-Customization-Tutorial).

Closed 2022-04-02.

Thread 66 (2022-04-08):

Right hand RigidMount of prototype 4 does not have a download button

TechnicallyOffbeat, 2022-04-08:
Prototype 4's [left hand](https://github.com/LucidVR/lucidgloves/blob/main/hardware/Prototype4/RigidMount_leftHand.STL) rigid mount has a download button and seems to be working as intended.
The [right hand](https://github.com/LucidVR/lucidgloves/blob/main/hardware/Prototype4/RigidMount_rightHand.STL) rigid mount does not have a download button, and is significantly larger for a file that should be basically the same as the left (76KB vs 374KB).

Burritoclock, 2022-04-14:
Same issue here

danwillm, 2022-04-14:
it is recommended to download the entire repository, then use the files from the download. You can download the repo by pressing the green code button on the homepage, then pressing download zip.

Closed 2022-04-14.

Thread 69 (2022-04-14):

Firmware cannot be compiled when using a different esp32 eg(heltec esp32 wifi)

AikoKiss, 2022-04-14:
Leaves error like Led not a type if not compiled with esp32dev

JohnRThomas, 2022-04-14:
Please open this issue on my fork as the problem is there :)

https://github.com/JohnRThomas/FlexiaGloves/pulls

@danwillm I think you can close this

danwillm, 2022-04-14:
Cool, thanks, will do!

Closed 2022-04-14.

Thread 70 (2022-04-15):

Can not download hardware/Prototype4/RigidMount_rightHand.STL pls help

JimmyTheRandomEgg, 2022-04-15:
when I go to download RigidMount_rightHand.STL it apperas as black and wont let me download it. pls HELP

danwillm, 2022-04-16:
It's recommended to download the entire repository, that way you have all the files stored locally.

You can do so by clicking the green code button at the homepage of the repo, then pressing download zip.

Closed 2022-04-16.

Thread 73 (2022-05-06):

Problem with uploading program to esp32 wroom 32u

fionn77, 2022-05-06:
hi,
somehow I'm not able to upload a program to the esp32 wroom 32u.
I'm using the Arduino version 2.0.0-rc6 and I also got the esp32 libraries installed.

fionn77, 2022-05-06:
sorry for the issue message problem has been fixed

LittleNyanCat, 2022-05-06:
Then you can close this issue

Closed 2022-05-06.

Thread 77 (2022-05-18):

10 bit analog resolution

CTRL-ALT-D3L, 2022-05-18:
Why do we have different analog resolutions on the esp and nano? It would be simpler to just set them both to 10 bits with `analogReadResolution(10);` in setup

LittleNyanCat, 2022-05-18:
Throwing away those two bits lowers the ESP's resolution by a whopping 75%...  ..and there's really not a good reason to do that.

CTRL-ALT-D3L, 2022-05-18:
There is a difference between resolution and accuracy. Unfortunately the ADC is not very accurate on the esp32 in any case.
The benefit is that it makes it standard and the user doesn't have to set it in the UI, which admittedly aren't really big deals, but its very trivial to implement so I thought it was worth a shot

LittleNyanCat, 2022-05-18:
> The UI is designed to be used with other firmwares and softwares other than lucidgloves, that max analog option is unlikely to go away for the foreseeable future.

CTRL-ALT-D3L, 2022-05-18:
Oh ok. Makes sense

Closed 2022-05-18.

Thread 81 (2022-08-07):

No printing Guide

dschmidt004, 2022-08-07:
There is no printing guide available

LittleNyanCat, 2022-08-07:
Yes there is: https://github.com/LucidVR/lucidgloves/wiki/Parts-Printing-Guides

dschmidt004, 2022-08-09:
Yep the link you gave me works but the link on the ReadMe is broken. Anyways thanks for the link I'm happy

Closed 2022-08-07.

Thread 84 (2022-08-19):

Part tolerance too loose

Leapo, 2022-08-19:
The couplers on Prototype 4 RigidMount_leftHand and RigidMount_rightHand appear to be too small to appropriately interface with any of the models that are meant to slide on and snap into place.

See photo for example: https://imgur.com/a/Xu4R0Nq

The fit is so loose between parts that the attached part never snap-fits into place, can slide/rotate a large amount, and will simply fall off of the RigidMount if turned sideways.

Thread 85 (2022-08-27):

Is this the right place to ask questions about parts?

Snailedlt, 2022-08-27:
I was looking for discussions, but notice you don't have any, so as a 2nd choice I opted for writing an issue instead, sorry if this is the wrong place to ask.

Anyways, I am looking through the parts list, and I see a few of the items don't have links, and some have amazon links only. I'm a software developer and have no experience with engineering or engineering parts, so please excuse my lack of knowledge in these things :)

Here's a list of the things I'm wondering about specifically:
1. The velcro straps. I don't know what to get, since I don't know the length or type to get, a link would be very helpful as a guideline.
2. The crimp set with only an amazon link, which has super expensive shipping and toll here in Norway. I was wondering if this is a good alternative to that: https://a.aliexpress.com/_mtOFRWo
3. The powerbank. I see the one you recommend is 20000 mAh, but do you really need that much? How long does 20000mAh last usually? Would prefer to have a smaller powerbank if it's viable.
4. MG90S doesn't have an aliexpress link, but I'm assuming this is the right one: https://a.aliexpress.com/_mL9ymPO
5. Found these retractable badge reels. Do they look good enough? https://a.aliexpress.com/_mrq9OXe

RyanTripleSeven, 2022-10-25:
Hey!

1. Velcro Straps.[These](https://www.aliexpress.us/item/3256801412856833.html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) should work, and you can select the size you need. Just measure the circumference of your wrist.
2. That crimping set looks fine
3. I guess you technically don't need 20000mAh, I'm using a 5000mAh after all, but it's good to have it last long.
4. those servos look fine.
5. So do the badge reels.

Snailedlt, 2022-10-25:
Thanks, this helps a lot! :)
How long is the battery life with your 5000mAh battery if you don't mind me asking?

RyanTripleSeven, 2022-10-25:
I haven't completely drained the batteries, as I always charge after use, but I've easily gotten 2 hours from it.

Snailedlt, 2022-10-26:
Alright, thanks! Then there's no need for anything larger than 10000mAh imo :)

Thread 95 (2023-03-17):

commulation problesms

dwj66, 2023-03-17:
 I have made a completely same glove (left) as your Prototype 4, but when I connected it with SteamVR (and vive focus 3) through serial communication, it always failed, and I cannot calibrate servo using the opengloves tools, can you help me with that?

danwillm, 2023-03-17:
Please head over to our discord server and open up a support ticket there along with some additional info, including log files from here: C:\Program Files (x86)\Steam\logs\vrserver.txt so we can better assist you.

dwj66, 2023-03-20:
Fri Mar 17 2023 16:44:09.586 - //==============================================================================================
Fri Mar 17 2023 16:44:09.586 - ================================================================================================
Fri Mar 17 2023 16:44:09.586 - ================================================================================================
Fri Mar 17 2023 16:44:09.586 - vrserver.exe 1.25.5 startup with PID=25504, config=D:\VR\steam\config, runtime=D:\VR\steaminstallation\steamapps\common\SteamVR
Fri Mar 17 2023 16:44:09.586 - [vrserver] watchdogs enabled
Fri Mar 17 2023 16:44:09.588 - CSharedResourceNamespaceServer starting up
Fri Mar 17 2023 16:44:09.588 - WaitNamedPipe SteamVR_Namespace failed because no one is listening at that name.
Fri Mar 17 2023 16:44:09.589 - CSharedResourceNamespaceClient::Init(): failed connect
Fri Mar 17 2023 16:44:09.589 - CSharedResourceNamespaceClient::Init(): still waiting for vrserver to reply with namespace data
Fri Mar 17 2023 16:44:09.589 - Set thread FFFFFFFFFFFFFFFE priority to: 1
Fri Mar 17 2023 16:44:09.589 - Set thread FFFFFFFFFFFFFFFE priority to: -15
Fri Mar 17 2023 16:44:09.633 - Connecting client (SteamVR_Namespace) app container status: 1
Fri Mar 17 2023 16:44:09.633 - CSharedResourceNamespaceServer sent namespace data: 25504
Fri Mar 17 2023 16:44:09.695 - Client (SteamVR_Namespace) app container state: 1
Fri Mar 17 2023 16:44:09.711 - Connecting client (SteamVR_Namespace) app container status: 1
Fri Mar 17 2023 16:44:09.711 - CSharedResourceNamespaceServer sent namespace data: 25504
Fri Mar 17 2023 16:44:09.711 - CSharedResourceNamespaceClient::Init(): received namespace data 25504
Fri Mar 17 2023 16:44:09.711 - Self queried namespace: 25504
Fri Mar 17 2023 16:44:09.711 - VR server 1.25.5 (v1678993434) starting up with config=D:\VR\steam\config
Fri Mar 17 2023 16:44:09.711 - VRServer will wait for VRMonitor before exiting
Fri Mar 17 2023 16:44:09.715 - Skipping external driver D:\VR\steam\steamapps\common\OpenGlove because it is not a directory
Fri Mar 17 2023 16:44:09.716 - [Settings] Load Default Json Settings from D:\VR\steaminstallation\steamapps\common\SteamVR\drivers\htc\resources\settings\default.vrsettings
Fri Mar 17 2023 16:44:09.716 - [Settings] Load Default Json Settings from D:\VR\steaminstallation\steamapps\common\SteamVR\drivers\lighthouse\resources\settings\default.vrsettings
Fri Mar 17 2023 16:44:09.716 - [Settings] Load Default Json Settings from D:\VR\steaminstallation\steamapps\common\SteamVR\drivers\null\resources\settings\default.vrsettings
Fri Mar 17 2023 16:44:09.717 - [Settings] Load Default Json Settings from D:\VR\VIVE Business Streaming\RRDriver\htc_business_streaming\resources\settings\default.vrsettings
Fri Mar 17 2023 16:44:09.717 - [Settings] Load Default Json Settings from D:\VR\steaminstallation\steamapps\common\OpenGlove\resources\settings\default.vrsettings
Fri Mar 17 2023 16:44:09.717 - [Settings] Load Default Json Settings from D:\VR\steaminstallation\steamapps\common\SteamVR\resources\settings\default.vrsettings
Fri Mar 17 2023 16:44:09.718 - [Settings] Load Json Settings from D:\VR\steam\config\steamvr.vrsettings
Fri Mar 17 2023 16:44:09.722 - [Settings] Load Default Json Settings from D:\VR\steaminstallation\steamapps\common\SteamVR\drivers\htc\resources\settings\default.vrsettings
Fri Mar 17 2023 16:44:09.722 - [Settings] Load Default Json Settings from D:\VR\VIVE Business Streaming\RRDriver\htc_business_streaming\resources\settings\default.vrsettings
Fri Mar 17 2023 16:44:09.722 - [Settings] Load Default Json Settings from D:\VR\steaminstallation\steamapps\common\SteamVR\drivers\lighthouse\resources\settings\default.vrsettings
Fri Mar 17 2023 16:44:09.722 - [Settings] Load Default Json Settings from D:\VR\steaminstallation\steamapps\common\OpenGlove\resources\settings\default.vrsettings
Fri Mar 17 2023 16:44:09.723 - [Settings] Load Default Json Settings from D:\VR\steaminstallation\steamapps\common\SteamVR\drivers\null\resources\settings\default.vrsettings
Fri Mar 17 2023 16:44:09.723 - [Settings] Load Default Json Settings from D:\VR\steaminstallation\steamapps\common\SteamVR\resources\settings\default.vrsettings
Fri Mar 17 2023 16:44:09.723 - [Settings] Load Json Settings from D:\VR\steam\config\steamvr.vrsettings
Fri Mar 17 2023 16:44:09.745 - Adding controller type vive
Fri Mar 17 2023 16:44:09.746 - Adding controller type rift
Fri Mar 17 2023 16:44:09.746 - Adding controller type indexhmd
Fri Mar 17 2023 16:44:09.746 - Adding controller type vive_controller
Fri Mar 17 2023 16:44:09.747 - Adding controller type oculus_touch
Fri Mar 17 2023 16:44:09.747 - Adding controller type knuckles
Fri Mar 17 2023 16:44:09.749 - Add Json firmware manifest from {htc}/firmware/manifest.vrfirmware
Fri Mar 17 2023 16:44:09.749 - Add Json firmware manifest from {indexcontroller}/firmware/manifest.vrfirmware
Fri Mar 17 2023 16:44:09.749 - Add Json firmware manifest from {indexhmd}/firmware/manifest.vrfirmware
Fri Mar 17 2023 16:44:09.749 - Add Json firmware manifest from {lighthouse}/firmware/manifest.vrfirmware
Fri Mar 17 2023 16:44:09.750 - Add Json firmware manifest from {tundra_labs}/firmware/manifest.vrfirmware
Fri Mar 17 2023 16:44:09.750 - Web language is schinese
Fri Mar 17 2023 16:44:09.750 - [Web] Starting web server on port 27062
Fri Mar 17 2023 16:44:09.751 - Caching webfont D:\VR\steaminstallation\steamapps\common\SteamVR\resources\webinterface\fonts\motiva-sans-black-italic.ttf.
Fri Mar 17 2023 16:44:09.755 - Caching webfont D:\VR\steaminstallation\steamapps\common\SteamVR\resources\webinterface\fonts\motiva-sans-black-italic.ttf.
Fri Mar 17 2023 16:44:09.758 - Caching webfont D:\VR\steaminstallation\steamapps\common\SteamVR\resources\webinterface\fonts\motiva-sans-black.ttf.
Fri Mar 17 2023 16:44:09.761 - Caching webfont D:\VR\steaminstallation\steamapps\common\SteamVR\resources\webinterface\fonts\motiva-sans-bold-italic.ttf.
Fri Mar 17 2023 16:44:09.765 - Caching webfont D:\VR\steaminstallation\steamapps\common\SteamVR\resources\webinterface\fonts\motiva-sans-bold.ttf.
Fri Mar 17 2023 16:44:09.768 - Caching webfont D:\VR\steaminstallation\steamapps\common\SteamVR\resources\webinterface\fonts\motiva-sans-extrabold-italic.ttf.
Fri Mar 17 2023 16:44:09.771 - Caching webfont D:\VR\steaminstallation\steamapps\common\SteamVR\resources\webinterface\fonts\motiva-sans-extrabold.ttf.
Fri Mar 17 2023 16:44:09.774 - Caching webfont D:\VR\steaminstallation\steamapps\common\SteamVR\resources\webinterface\fonts\motiva-sans-light-italic.ttf.
Fri Mar 17 2023 16:44:09.777 - Caching webfont D:\VR\steaminstallation\steamapps\common\SteamVR\resources\webinterface\fonts\motiva-sans-light.ttf.
Fri Mar 17 2023 16:44:09.779 - Caching webfont D:\VR\steaminstallation\steamapps\common\SteamVR\resources\webinterface\fonts\motiva-sans-medium-italic.ttf.
Fri Mar 17 2023 16:44:09.782 - Caching webfont D:\VR\steaminstallation\steamapps\common\SteamVR\resources\webinterface\fonts\motiva-sans-medium.ttf.
Fri Mar 17 2023 16:44:09.784 - Caching webfont D:\VR\steaminstallation\steamapps\common\SteamVR\resources\webinterface\fonts\motiva-sans-regular-italic.ttf.
Fri Mar 17 2023 16:44:09.787 - Caching webfont D:\VR\steaminstallation\steamapps\common\SteamVR\resources\webinterface\fonts\motiva-sans-regular.ttf.
Fri Mar 17 2023 16:44:09.789 - Caching webfont D:\VR\steaminstallation\steamapps\common\SteamVR\resources\webinterface\fonts\motiva-sans-thin-italic.ttf.
Fri Mar 17 2023 16:44:09.792 - Caching webfont D:\VR\steaminstallation\steamapps\common\SteamVR\resources\webinterface\fonts\motiva-sans-thin.ttf.
Fri Mar 17 2023 16:44:09.794 - Caching webfont D:\VR\steaminstallation\steamapps\common\SteamVR\resources\webinterface\fonts\motiva-sans.ttf.
Fri Mar 17 2023 16:44:09.797 - Connecting client (VR_ServerPipe_25504) app container status: 1
Fri Mar 17 2023 16:44:09.797 - New Connect message from D:\VR\steaminstallation\steamapps\common\SteamVR\bin\win32\vrstartup.exe (VRApplication_Bootstrapper) (Args: ) 6872
Fri Mar 17 2023 16:44:09.802 - Creating Builtin AppInfo for D:\VR\steaminstallation\steamapps\common\SteamVR\bin\win32\vrstartup.exe (VRApplication_Bootstrapper). steam.overlay.250820, , 6872
Fri Mar 17 2023 16:44:09.802 - AppInfoManager.ProcessConnected BEGIN 6872 D:\VR\steaminstallation\steamapps\common\SteamVR\bin\win32\vrstartup.exe 7 steam.overlay.250820
Fri Mar 17 2023 16:44:09.807 - SetApplicationPid appkey=steam.overlay.250820 pid=6872, external transition
Fri Mar 17 2023 16:44:09.807 - SetApplicationPid: Setting app steam.overlay.250820 PID to 6872
Fri Mar 17 2023 16:44:09.807 - AppInfoManager.ProcessConnected END
Fri Mar 17 2023 16:44:09.807 - Enabling legacy input for steam.overlay.250820
Fri Mar 17 2023 16:44:09.811 - htc_business_streaming: Driver start : 10394174619
Fri Mar 17 2023 16:44:09.811 - htc_business_streaming: Connect to rrServer
Fri Mar 17 2023 16:44:09.812 - htc_business_streaming: HandleDeviceConnect 0 1 FOCUS3
Fri Mar 17 2023 16:44:09.812 - htc_business_streaming: hmd name is : FOCUS3 vs [FOCUS3]
Fri Mar 17 2023 16:44:09.812 - htc_business_streaming: Get adapter LUID 0
Fri Mar 17 2023 16:44:09.906 - htc_business_streaming: [htc_business_streaming] Traget window w:2048, h:2048
Fri Mar 17 2023 16:44:09.909 - htc_business_streaming: Get device FPS 90.0.
Fri Mar 17 2023 16:44:09.909 - Driver 'htc_business_streaming' started activation of tracked device with serial number 'FOCUS3'
Fri Mar 17 2023 16:44:09.909 - htc_business_streaming: Driver's pipe is enable!
Fri Mar 17 2023 16:44:09.909 - htc_business_streaming: Driver Path is D:\VR\VIVE Business Streaming\RRDriver\htc_business_streaming\bin\win64\driver_htc_business_streaming.dll
Fri Mar 17 2023 16:44:09.909 - htc_business_streaming: Resource Path: D:\VR\VIVE Business Streaming\RRDriver\htc_business_streaming\resources\rendermodels\tracker, exist: 1
Fri Mar 17 2023 16:44:09.909 - htc_business_streaming: RR Driver version: 1.0.23.19
Fri Mar 17 2023 16:44:09.909 - htc_business_streaming: vrServer Path is D:\VR\steaminstallation\steamapps\common\SteamVR\bin\win64\vrserver.exe
Fri Mar 17 2023 16:44:09.910 - htc_business_streaming: [OnPipeData] Receive CMD_HAND_STRUCT_VER [0]
Fri Mar 17 2023 16:44:09.910 - htc_business_streaming: [OnPipeData] Receive CMD_TREACKER_COMPATIBLE [1]
Fri Mar 17 2023 16:44:09.910 - htc_business_streaming: [OnPipeData]Receive CMD_DASHBOARD_FLAG [1]
Fri Mar 17 2023 16:44:09.910 - htc_business_streaming: [OnPipeData] Receive CMD_HAND_STRUCT_VER [0]
Fri Mar 17 2023 16:44:09.910 - htc_business_streaming: [OnPipeData] Receive CMD_TREACKER_COMPATIBLE [1]
Fri Mar 17 2023 16:44:09.910 - htc_business_streaming: [OnPipeData]Receive CMD_DASHBOARD_FLAG [1]
Fri Mar 17 2023 16:44:09.910 -   driver htc_business_streaming implements interfaces IVRSettings_003 ITrackedDeviceServerDriver_005 IVRDisplayComponent_002 IVRDriverDirectModeComponent_007 IVRCameraComponent_003 IServerTrackedDeviceProvider_004 IVRWatchdogProvider_001 IVRVirtualDisplay_002 IVRDriverManager_001 IVRResources_001 IVRCompositorPluginProvider_001
Fri Mar 17 2023 16:44:09.910 - Loaded server driver htc_business_streaming (IServerTrackedDeviceProvider_004) from D:\VR\VIVE Business Streaming\RRDriver\htc_business_streaming\bin\win64\driver_htc_business_streaming.dll
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

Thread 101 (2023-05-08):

Can't get lucidgloves to work with steamVR

m4tustechna, 2023-05-08:
Hello. I recently put together LucidVR LucidGloves Prototype 4. I assembled the virtual reality gloves according to "How to build cheap VR Haptic Gloves to FEEL VR." video by Lucas. I'm now on the part where I have to set up the driver to work with SteamVR.

In the Arduino IDE, when I open the Serial Monitor, I can see the data correctly and I know the potentiometers on the gloves work. I've installed OpenGloves from steam and set the data correctly (I hope). When I start SteamVR, I can see the glove icons, which are greyed out. The opengloves driver doesn't emulate the Steam Index drivers.

I also want to mention that instead of Oculus controllers I have HTC Vive Trackers and instead of arduino nano I have ESP-WROOM-32. ESPs are set to bluetooth.

One thing I know is that the ESP32 communicates with the OpenGloves driver. When I click "functions" > "servo testing...", I can move the motors. They take about 30 seconds before I can press the button again, but they work.

I don't know what to do and I really need help, if possible please answer me asap

Thanks in advance
- Matt

m4tustechna, 2023-05-08:
[vrserver.txt](https://github.com/LucidVR/lucidgloves/files/11422661/vrserver.txt)

m4tustechna, 2023-05-08:
I managed to figure out the next step I was supposed to do. I had to change the override data.

Followed this : https://github.com/LucidVR/opengloves-driver/wiki/Configuring-the-Driver#tracking-overrides

Changed in Opengloves UI and manually, located at /steamapps/common/OpenGlove/resources/settings/default.vrsettings

Now, instead of grey, my gloves are flashing and SteamVR says "searching". Web console says it's paired with a bluetooth device

`Mon May 08 2023 18:50:51.518 - openglove: Bluetooth Device found (lucidgloves-right)
Mon May 08 2023 18:50:51.518 - openglove: Bluetooth Device is authenticated (lucidgloves-right)
Mon May 08 2023 18:50:52.569 - openglove: Connected to bluetooth (lucidgloves-right)`

It's progress but I still can't pair the gloves

lucas-vrtech, 2023-05-09:
It sounds like you don't have your vive trackers configured properly. Instead of using the override feature, try configuring your vive trackers as left and right hands. Under Manage Vive Trackers, set them as left and right hands.

m4tustechna, 2023-05-09:
I got it! I found out what the problem was. The problem was that I hadn't set the trackers to behave like controllers. I did try this before I wrote this issue on github, but I failed. The reason I failed is because I was trying to configure the reciever and not the tracker. Thanks Lucas for the pointers, that there was no fault other than that I set the trackers incorrectly

I might as well share what I have done for those who are still lost.

I used this post on reddit : https://www.reddit.com/r/beatsaber/comments/bn6e4u/ragesaqs_school_of_making_a_vive_tracker_maul/
Follow only part 1!

Unplug any VR devices and plug trackers directly with USB cable (make sure you can use those cables for data transfer and that they are not just for charging)
Just in case, make backup of the .json file.
open the opengloves driver, reset the settings and then enter the serial number of the tracker in "Device Driver Emulation"

Closed 2023-05-09.

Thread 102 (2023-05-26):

Linux support?

ARPavel22, 2023-05-26:
Hi, thank you for this big work!

Now im trying to compile Steam VR drive for LINUX Platform.
I have some succes.
But need some work to move Windows functions like NAMED PIPE and othrer.

Maybe you or anyone Developer made it?
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

ARPavel22, 2023-05-31:
I managed! In general, I will answer my own question. Yes, open glove works on linkuks. Ubuntu 22.04. It only took to cut out all the extra stuff like bluetooth and serial and rewrite the pipe system.

ARPavel22, 2023-05-31:
![Uploading IMG_20230531_120108_440.jpg…]()

ARPavel22, 2023-05-31:
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

danwillm, 2023-05-31:
Nice, feel free to open a PR to the opengloves repo with your changes!

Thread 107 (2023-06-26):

gloves dont connect

ny1u, 2023-06-26:
I use esp32 , with a ch340c converter. The firmware was successful, changed to bluetooth connection, but when I try to connect the gloves writes that there is no response from the device. Tried to connect by wire , also nothing works. I think the problem is in the ch340c.
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

LittleNyanCat, 2023-06-26:
If the firmware was successfully flashed, then that means the CH340C worked without any issue. Bluetooth is completely independent of the hardware serial interface so it has nothing to do with the CH340C either...
Is Bluetooth dongle is version 4.0? Newer versions are known to cause issues with the ESP32

ny1u, 2023-06-26:
Dongle version is 5.0

LittleNyanCat, 2023-06-26:
That is a probably cause for the Bluetooth issue, however you should still be able to test it in serial mode (via USB cable)

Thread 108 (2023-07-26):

CV1 controller tracking

Whheat, 2023-07-26:
I’m yet to built my gloves as I’m waiting for the next prototype but could you theoretically use the Rift CV1 controllers for tracking? I’ve heard legends of how excellent the controllers are and how durable they are. I feel like it could be done if I had the cameras set up right so the tracking rings facing upward could be tracked.

lucas-vrtech, 2023-07-29:
Yes! The CV1 controllers are awesome for VR gloves.
In fact, back in prototype 3 and earlier, [that was my preferred way of tracking the gloves.](https://www.tiktok.com/@lucas_vrtech/video/6926639197319171333)

That being said, I don't know of any way to use the CV1 controllers without also using the CV1 HMD.

Closed 2023-07-29.

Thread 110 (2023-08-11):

Haptic feedback not working

Marina22123, 2023-08-11:
After about five times retracting and extending the servos it suddenly stops working. I can't extend or retract them anymore and if I open the demo and try to pick something up it extends the servos automatically even if I didn't grab the item. I just slightly touched the cube... The glove just stays that way and if I try to retract them again with Openglove it doesn't work. Sometimes it even shows an "error". It seems like that the ESP crashed somehow. Can someone help me? I'm using bluetooth communication.

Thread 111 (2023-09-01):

My computer doesn't see the glove in the bluetooth settings

AllSuperHeroes, 2023-09-01:
I am using a esp32 wroomu with an external antenna and my computer doesn't  see the glove when I try to add new Bluetooth device

AllSuperHeroes, 2023-09-01:
apparently my esp32's Bluetooth wasn't working

Closed 2023-09-01.

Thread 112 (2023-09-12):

When I connect with Bluetooth, I always disconnect, I can't connect, and I can't track my location in real time when I connect with USB. Is there a wiring problem?

Yangcrazy1, 2023-09-12:
When I connect with Bluetooth, I always disconnect, I can't connect, and I can't track my location in real time when I connect with USB. Is there a wiring problem?

AlexFEIII, 2023-09-30:
Have you solved this issue?  I have the same issue as you

japanjot381, 2023-10-05:
It's the samee issue with me , found any solution? I even can't use it on wired mode , whenever i open opengloves and in wired mode and want to expand servos " 404 error not found" something like that error pops out.

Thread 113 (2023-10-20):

Using only haptic feedback

cllkvv, 2023-10-20:
Hey guys, I am working on a school project which requires me to use leapmotion for my hand tracking. Anyone knows how to just use the haptic feedback aspect of the gloves and not need the handtracking? Thank you.

LittleNyanCat, 2023-10-20:
You could just not add the potentiometers and leave those pins floating on the ESP32, then ignore the garbled finger data the gloves will put out in your app. If plan to make your app work with SteamVR that may be a problem since Opengloves spawns it's own controllers and you don't have a direct way of overriding the finger values it gets from the gloves, you'll have to work around that somehow.

I think you may have a bigger issue though - I'm not sure LeapMotion will be able to track your gloves when they have a bunch of stuff strapped to them, which occludes the hand itself... Remember that the LeapMotion is purely optical.

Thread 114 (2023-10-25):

Hello friends, I am a student from China. I made a one-handed glove, but I couldn't get feedback from ALEX. How can I solve it

Yangcrazy1, 2023-10-25:
Hello friends, I am a student from China. I made a one-handed glove, but I couldn't get feedback from ALEX. How can I solve it？and sometimes can't grasp the object

MasterSiu, 2023-10-25:
You have to download plug in for the half life on lucid glove page

Yangcrazy1, 2023-10-25:
> 您必须在清醒手套页面上下载半衰期插件

Yes, I downloaded and opened ALEX, but I only have one glove, can only grab objects but can't generate force feedback, what is the reason for this can be solved?

Yangcrazy1, 2023-10-25:
923925220@qq.com 如果您了解怎么解决可以发邮件联系我

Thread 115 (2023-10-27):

Quest 3?

TheBlueOompaLoompa, 2023-10-27:
I'm part of a group that's looking to build a set of these gloves for a project. We're currently deciding which headset to purchase, but we don't know if these work on quest 3. I'm guessing the shape is close enough where the mount will still work, but I'm worried about tracking. From what I read, it looks like they use combination hand tracking and a few IR light tracking points. I'm concerned it won't be able to track when the lights are occluded because hand tracking may not work. Has anyone tested this yet?

MasterSiu, 2023-10-27:
It doesn't work outside steam vr at the moment

TheBlueOompaLoompa, 2023-10-27:
I should clarify, I am writing a custom driver to connect it to quest headsets in my unity project, but I was wondering if someone had tested it in Steam VR with quest link. Specifically because the new method for controller tracking seems to rely on hand tracking to fill in for when the tracking lights were occluded.

danwillm, 2023-10-27:
When using the steamvr driver we've developed for the gloves, quest 3 is supported fine.

Closed 2023-10-27.

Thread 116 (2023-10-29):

Serial mointer working on v4 but not v5

yungfresh1hub, 2023-10-29:
Hi, I am making the v5, a few months back when I began, I flashed the v5 firmware to the esp32 then it worked. But now the serial monitor updates but the data does not chage, I have tried reflashing other esp32 but nothing worked besides the buttons. But when I flash the v4 firmware the serial motor updates like it should. Any fix? also my hall sensor and mux are working as the should when i test them in other projects

m4tustechna, 2023-12-23:
Excuse me, but where did you download the v5 firmware from ?
I am also working on LucidGloves prototype 5 but I can't find where I can download the new firmware. Is it on discord ?

giovannylimin, 2024-02-20:
Hi, do you remember which v5 firmware that worked? Thank you

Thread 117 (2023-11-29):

Hall effect sensor (rotary encoder) for the V5

borgsm1, 2023-11-29:
Hi, may I suggest using the sensor AS5600 by Osram.

Similar to Marius Heier's project making a drop in replacement for a thumbstick and would use a ring magnet.
He criticized that using a linear hall effect sensor would have an inconsistent measurement but using the the chip would measure better as it is measuring the angle of the magnet.
It looks like it will fit in better with your design.
It can work like an analog pot or could be digital.

borgsm1, 2023-11-29:
As an analog pot it can be programmed to have more resolution against an actual potentiometer. And when programmed to work like an analog pot there would be no need to modify the gloves v4 code.

Or as a digital pot it would communicate directly with the microcontroller.

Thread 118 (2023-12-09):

Nothing In serial Monitor

AlbyYoutube, 2023-12-09:
Proto 5 has a software issue somewhere because me and numerous other people are having issues with proto 5 not tracking the hall sensors.

Closed 2023-12-16.

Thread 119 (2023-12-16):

V4 middle pot is backward

AlbyYoutube, 2023-12-16:
How can I change the Middle pot direction only. The servo was moving backwards when I made it, so I reprinted the spool mirrored and this fixed the servo but now the middle finger is open when mine is closed and vice versa.

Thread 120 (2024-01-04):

Adding IR LED's around wrist to provide quest tracking

JoelsephBW, 2024-01-04:
Any chance this could be implemented? See title. I'm thinking quest 2/3 if it's possible had it based tracking for the controllers, just making it track the wrist should provide a significant uptick in positional tracking right? Or maybe wrist+ back of the hand and maybe a different pattern for the palm? Maybe even finger tips? Or is that just pointlessly redundant? Since it already estimated finger position off of the potentiometer? I mean it might provide better splay sensing too...

Tldr:
 would ir leds be an option to implement tracking in quest 2/3?

And how would I go about getting native non PC implementation of this if it will hypothetically work?

valzzu, 2024-01-13:
Dont think so

RedHawk989, 2024-03-25:
It's not possible to do that. (Meta is too locked down for this to happen natively). most you could do is take apart a controller, but you still would need to maintain it's IR LED placement geometry.

You _could_ attempt a pcvr custom solution to do this, but you'd need separate cams wired to a PC, and lots of time to tune algorithms, make controller drivers, and figure stuff out. Doesn't make sense for this project to attempt on its own.

AthemiS13, 2024-12-12:
you can use hand tracking

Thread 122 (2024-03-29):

What is pin32 being used for?

DieKatzchen, 2024-03-29:
There's a couple spots in _main.ino where pin32 is referenced as a magic number. This is the main thing stopping compatibility with ESP32S3, as pin32 is used internally for the system flash. What is it being used for and can it be replaced with a configuration item?

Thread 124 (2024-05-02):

Wiki - Prototype 5 build guide images no longer valid

phillips-tech, 2024-05-02:
https://github.com/LucidVR/lucidgloves/wiki/Prototype-5-BETA-Assembly-Guide

The images are no longer available - for example: https://media.discordapp.net/attachments/1014992969494974607/1054853648070488215/IMG_3479.jpg
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

Skyibis, 2024-06-22:
^ Agree with this, I was able to recover them by pasting them directly into Discord. Might put in a PR with this fixed.

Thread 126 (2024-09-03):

Is this project abandoned?

Wilaz, 2024-09-03:
Its been over a year since the last commit, and nearly two years since and major updates. Is there still active work being put into this or is prototype 5 becoming a Half-Life: 3?

Corbett000, 2024-09-03:
From what I have seen there has been little to no communication with the creator Lucas in the past 9 months. I know that there are still some plans for Prototype 5, but they might have to be completed by community members.

The discord server (https://discord.gg/lucidvr) is still active if you want to talk and ask questions, and I know there are a couple of upgrades like Fae Mod that help to improve prototype 5.

DieKatzchen, 2024-09-04:
I made a pull request back in April. He contacted me and said he'd look at it when he had some free time. Unfortunately MIT and Free Time don't exactly go hand-in-hand.

adabru, 2025-01-02:
I think the project is still hot, it would be nice if somebody could pick it up. Today I'm applying for the German "prototypefund" to get sponsored for work on lucidvr. More specifically, I'm applying for funds to update lucidvr's driver to OpenXR and help with the BLE part.

Apart from that, if anyone is willing to take over (part of) the project, I would contribute a small monthly donation.

danwillm, 2025-01-02:
> I think the project is still hot, it would be nice if somebody could pick it up. Today I'm applying for the German "prototypefund" to get sponsored for work on lucidvr. More specifically, I'm applying for funds to update lucidvr's driver to OpenXR and help with the BLE part.
>
> Apart from that, if anyone is willing to take over (part of) the project, I would contribute a small monthly donation.

I can only talk for opengloves: I wouldn't say it's abandoned - I am still more than happy to help with questions that people have with the code and am also happy to review contributions.

A lot of projects (and companies) now actively ship opengloves - or have at least incorporated it into their codebase - to make their gloves compatible with SteamVR and I've continued to help with questions these vendors have.

It's great to hear that you're keen on developing opengloves; feel free to let me know if you have any questions. Opengloves already supports OpenXR through SteamVR, but unfortuantely there currently doesn't exist a spec to make drivers native for OpenXR. Supporting BLE would be very neat, and will be happy to review any changes you make. Feel free to keep me in the loop 🙂.

adabru, 2025-01-03:
@danwillm thank you very much for your work! I guess you're talking about https://github.com/LucidVR/opengloves-driver. Sorry if it sounded like I said this project is abandoned. From what I've personally seen so far, this is (still) the most active open-source data glove driver.

What I meant was no one is dedicating time in the scale of 100h to implement major changes. I just glimpsed into the discord channels and GitHub issues, so my opinion is not very well-informed. I was thinking "the last commit is from 12.2023", "OpenVR is not supported by Quest standalone, the most prominent headset", "there is a BLE issue/PR from April that probably won't be finalized and merged".

> A lot of projects (and companies) now actively ship opengloves - or have at least incorporated it into their codebase - to make their gloves compatible with SteamVR and I've continued to help with questions these vendors have.

So super nice of you :), That's one of the things I planned to do if I'd got a grant for it.

> but unfortuantely there currently doesn't exist a spec to make drivers native for OpenXR

In the docs it says:

> We emulate the index controller to achieve this
compatibility, which means that we are limited
to the inputs that the index controller exposes.

It is referring to the OpenVR implementation, but Isn't the same possible for an OpenXR device? Emulating the index controller? And having a custom profile or a profile leaned on another hand tracking product as an extended alternative?

My hypothesis is:
- Migrating to OpenXR will make it compatible with the most popular headset, the Meta Quest, and other standalone headsets.
- With OpenXR it is more likely to run in monado versions on linux and macos without compatibility issues.

I don't have a prototype to verify or falsify these claims.

---

My personal dream is to replace my keyboard with a data glove, that's why I'm working actively with the data glove manufacturer Cynteract in my free time so I can pursue my dream. If you know a project/company that is active in that direction, please let me know <3

> A lot of projects (and companies) now actively ship opengloves - or have at least incorporated it into their codebase - to make their gloves compatible with SteamVR and I've continued to help with questions these vendors have.

Do you have a list of them available?

danwillm, 2025-01-04:
Quest standalone cannot currently be supported as there isn't an interface available to write device drivers in OpenXR, or to load external layers on Quest.
As for Monado, I actually did implement a driver for that here: https://gitlab.freedesktop.org/monado/monado/-/tree/main/src/xrt/drivers/opengloves.

The gloves currently emulate index controllers, which means they appear to SteamVR as index controllers. SteamVR does the work translating between OpenVR and OpenXR, which means the gloves are supported when running OpenXR games with SteamVR.

Fwiw, this emulation of index controllers is not required anymore, and if you receive funding to work on the project you should consider switching to emulated controller bindings, see https://github.com/ValveSoftware/openvr/blob/master/docs/Driver_API_Documentation.md#application-compatibility

adabru, 2025-01-04:
Thanks :) I can see that I mixed up the OpenXR term.

Is the project title for the driver "opengloves-driver"? I guess LucidVR initially named it like that with it's SteamVR ITrackedDeviceServerDriver implementation. You extended the project with the Monado xrt_device implementation.

The driver interface to the input device is Bluetooth serial, USB serial and named pipes. BLE is approved.

The driver's other side is not so clear to me. Currently, it is implemented as Monado and SteamVR input device. It can potentially interface to:

- First-party game code.
- Third-party game-engine/input-library API.
- VR runtime API, e.g. Monado or SteamVR. Is this also possible for the other runtimes? Do they have equivalents to xrt_device and ITrackedDeviceServerDriver that can be hooked into the target device?
- Operating system via Firmware, i.e. the exposed USB and Bluetooth interface.

The target platform limits the supported VR runtime:

- Quest 2 Standalone game: OculusXR, OpenXR.
- Linux PC game: OpenXR via Monado, SteamVR via Proton.
- Windows Steam game: SteamVR , OculusXR, OpenXR.
- A generic Windows game: the above, plus WMR/Pimax/Varjo/VIVE/etc.

The choice of game engine limits the supported VR runtime as well:

- Godot 4.0: OpenXR. Deprecated support for OculusXR.
- Unity: OpenXR, OculusXR, SteamVR, WMR and Varjo XR. Deprecated support for GoogleVR and GearVR.
- Unreal: the above, plus Pico SDK.

According to https://docs.godotengine.org/en/stable/tutorials/xr/openxr_hand_tracking.html#the-hand-tracking-api and https://github.com/joemarshall/openxrhands there is an OpenXR API for hand tracking. Can the opengloves-driver expose a hand-tracking device and additionally a controller device to the OpenXR runtime?

---

I stopped writing the above text, it's gotten too much for my schedule at the moment.

> if you receive funding to work on the project you should consider switching to emulated controller bindings, see https://github.com/ValveSoftware/openvr/blob/master/docs/Driver_API_Documentation.md#application-compatibility

Would that mean something like: Bob starts a VR game. He plugs in his glove which implements the opengloves-driver. The driver queries the capabilities of the glove. Depending on that the driver registers it as knuckles-controller/valve-index/etc. and translates the inputs to inputs of that specific emulated controller?

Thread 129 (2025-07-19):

I designed an updated model.

Yang66g, 2025-07-19:
I am a 17-year-old student in China. I have designed a new prototype based on an earlier one, which connects with a buckle to the hand, making it more convenient to wear and also looks more elegant, with great potential for development. However, the problem is that due to a busy academic schedule, I do not have the time to improve it and can only keep it as a design on paper (I am not good at modeling, programming, etc.; design is my strength). Is there anyone interested in helping me?

JamieStar-was-taken, 2025-07-20:
Could you please provide the design on paper

Yang66g, 2025-07-20:
> 您能否提供纸上的设计
当然可以，但请给我一点时间

Anxin10, 2025-08-07:
I'm also from China. Would it be possible to connect more easily for communication?

Yang66g, 2025-08-07:
哥们你直接说中文呗，微信GTX690xx

Yang.
***@***.***

学生
中国

---Original---
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

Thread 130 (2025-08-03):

glove not sending data

davidomega2000, 2025-08-03:
the board I used worked before, but it suddenly isn't sending the numbers in the serial monitor.

rst:0x1 (POWERON_RESET),boot:0x13 (SPI_FAST_FLASH_BOOT)
configsip: 0, SPIWP:0xee
clk_drv:0x00,q_drv:0x00,d_drv:0x00,cs0_drv:0x00,hd_drv:0x00,wp_drv:0x00
mode:DIO, clock div:1
load:0x3fff0030,len:4744
load:0x40078000,len:15672
load:0x40080400,len:3152
entry 0x4008059c
is all that appears when i press the reset button

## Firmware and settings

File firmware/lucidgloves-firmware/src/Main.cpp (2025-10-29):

#include "Main.h"
#include "Communication/SerialCommunication.h"
#include "Communication/BTSerialCommunication.h"
#include "Encoding/AlphaEncoding.h"
#include "Encoding/LegacyEncoding.h"
#include "Util/DataStructs.h"

#define ALWAYS_CALIBRATING CALIBRATION_LOOPS == -1
#define CALIB_OVERRIDE false
#if USING_CALIB_PIN && COMMUNICATION == COMM_SERIAL && PIN_CALIB == 0 && !CALIB_OVERRIDE
  #error "You can't set your calibration pin to 0 over usb. You can calibrate with the BOOT button when using bluetooth only. Set CalibOverride to true to override this."
#endif

Main::Main() {
  // Constructor code here
}

void Main::setup() {
  pinMode(32, INPUT_PULLUP);
  pinMode(DEBUG_LED, OUTPUT);
  digitalWrite(DEBUG_LED, HIGH); 

  #if COMMUNICATION == COMM_SERIAL
    comm = new SerialCommunication();
  #elif COMMUNICATION == COMM_BTSERIAL
    comm = new BTSerialCommunication();
  #elif COMMUNICATION == COMM_WIFISERIAL
    comm = new WIFISerialCommunication();
  #else
    #error "Communication not set."
  #endif 

  #if ENCODING == ENCODE_ALPHA
    encoding = new AlphaEncoding();
  #elif ENCODING == ENCODE_LEGACY
    encoding = new LegacyEncoding();
  #else
    #error "Encoding not set."
  #endif

  
  comm->start();

  input.setupInputs();

  #if USING_FORCE_FEEDBACK
    haptics.setupServoHaptics();  
  #endif
  
  #if defined(ESP32_DUAL_CORE_SET)
    xTaskCreatePinnedToCore(
      Main::getInputsWrapper, /* Function to implement the task */
      "Get_Inputs", /* Name of the task */
      10000,  /* Stack size in words */
      this,  /* Task input parameter */
      tskIDLE_PRIORITY,  /* Priority of the task */
      &Task1,  /* Task handle. */
      0); /* Core where the task should run */
  #endif
}

void Main::loop() {
  
  if (comm->isOpen()){

    #if USING_CALIB_PIN
    data.calib = input.getButton(PIN_CALIB) != INVERT_CALIB;
    if (data.calib)
      loops = 0;
    #else
    data.calib = false;
    #endif
    if (loops < CALIBRATION_LOOPS || ALWAYS_CALIBRATING){
      calibrate = true;
      loops++;
    }
    else{
      calibrate = false;
    }

    #if !defined(ESP32_DUAL_CORE_SET)
      input.getFingerPositions(calibrate, data.calib, fingerPos);
    #endif
    data.joyClick = input.getButton(PIN_JOY_BTN) != INVERT_JOY;

    #if TRIGGER_GESTURE
    data.triggerButton = gesture.triggerGesture(fingerPos);
    #else
    data.triggerButton = input.getButton(PIN_TRIG_BTN) != INVERT_TRIGGER;
    #endif

    data.aButton = input.getButton(PIN_A_BTN) != INVERT_A;
    data.bButton = input.getButton(PIN_B_BTN) != INVERT_B;

    #if GRAB_GESTURE
    data.grab = gesture.grabGesture(fingerPos);
    #else
    data.grab = input.getButton(PIN_GRAB_BTN) != INVERT_GRAB;
    #endif

    #if PINCH_GESTURE
    data.pinch = gesture.pinchGesture(fingerPos);
    #else
    data.pinch = input.getButton(PIN_PNCH_BTN) != INVERT_PINCH;
    #endif

    int fingerPosCopy[10];
    int mutexTimeDone;
    data.menu = input.getButton(PIN_MENU_BTN) != INVERT_MENU;
    {
      #if defined(ESP32_DUAL_CORE_SET)
      int mutexTime = micros();
      //const std::lock_guard<std::mutex> lock(fingerPosMutex);
      fingerPosLock->lock();
      mutexTimeDone = micros()-mutexTime;
      #endif
      //memcpy(fingerPosCopy, fingerPos, sizeof(fingerPos));
      for (int i = 0; i < 10; i++){
        fingerPosCopy[i] = fingerPos[i];
      }
      #if defined(ESP32_DUAL_CORE_SET)
      fingerPosLock->unlock();
      #endif
      
    }

    memcpy(data.fingers, fingerPosCopy, 5 * sizeof(int));
    data.joyX = input.getJoyX();
    data.joyY = input.getJoyY();

    static char encodedString[100] = {0};
    encoding->encode(data, encodedString);
    comm->output(encodedString);
    #if USING_FORCE_FEEDBACK
      static char received[100];
      if (comm->readData(received)){
        int hapticLimits[5];
        //This check is a temporary hack to fix an issue with haptics on v0.5 of the driver, will make it more snobby code later
        if(String(received).length() >= 5) {
           DecodedData recievedData = encoding->decodeData(received);
           haptics.writeServoHaptics(recievedData.servoValues); 
           if (recievedData.fields.specialCommandReceived){
            Serial.println("Special command recieved!!!");
              if (recievedData.command == "ClearData")
                input.clearFlags();
              #if FLEXION_MIXING == MIXING_SINCOS
              else if (recievedData.command == "SaveInter")
                input.saveIntermediate();
              #endif
              else if (recievedData.command == "SaveTravel")
                input.saveTravel();
           }
        }
      }
    #endif
    #if defined(ESP32)
      vTaskDelay(LOOP_TIME);
    #else
      delay(LOOP_TIME);
    #endif
  }
}


#if defined(ESP32_DUAL_CORE_SET)
void Main::getInputs(){
    for(;;){
      {
        fingerPosLock->lock();
        input.getFingerPositions(calibrate, data.calib, fingerPos); //Save finger positions in thread

        fingerPosLock->unlock();
      }
      threadLoops++;
      if (threadLoops%100 == 0){
        vTaskDelay(1); //keep watchdog fed
      }
      delayMicroseconds(1);
    }           
}

void Main::getInputsWrapper(void* _this) {
  // Cast the void* parameter back to a Main* and call getInputs on it
  static_cast<Main*>(_this)->getInputs();
}

#endif

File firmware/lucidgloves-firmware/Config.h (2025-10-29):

#pragma once
#include "src/Util/ConfigUtils.h"
#include "AdvancedConfig.h"

//LUCIDGLOVES CONFIGURATION SETTINGS :)

//This is the configuration file, main structure in _main.ino
//CONFIGURATION SETTINGS:
#define COMMUNICATION COMM_SERIAL //Which communication to use. Options are: COMM_SERIAL (usb), COMM_BTSERIAL (bluetooth), COMM_WIFISERIAL (wifi)
//serial over USB
  #define SERIAL_BAUD_RATE 115200
  
//serial over Bluetooth
  #define BTSERIAL_DEVICE_NAME "lucidgloves-left"

// serial over WIFI
#if COMMUNICATION == COMM_WIFISERIAL
#define ssid "Your_Wifi_SSID";
#define password "Your_Wifi_Password";
#define host "Your_host_ip";
#define port 65432; // port of the tcp server
#endif

//ANALOG INPUT CONFIG
#define USING_SPLAY false //whether or not your glove tracks splay. - tracks the side to side "wag" of fingers. Requires 5 more inputs.
#define USING_MULTIPLEXER false //Whether or not you are using a multiplexer for inputs
#define FLIP_FLEXION  false  //Flip values from potentiometers (for fingers!) if they are backwards
#define FLIP_SPLAY true //Flip values for splay


//Gesture enables, make false to use button override
#define TRIGGER_GESTURE true
#define GRAB_GESTURE    true
#define PINCH_GESTURE   true


//BUTTON INVERT
//If a button registers as pressed when not and vice versa (eg. using normally-closed switches),
//you can invert their behaviour here by setting their line to true.
//If unsure, set to false
#define INVERT_A false
#define INVERT_B false
#define INVERT_JOY false
#define INVERT_MENU false
#define INVERT_CALIB false
//These only apply with gesture button override:
#define INVERT_TRIGGER false
#define INVERT_GRAB false
#define INVERT_PINCH false


//joystick configuration
#define JOYSTICK_BLANK true //make true if not using the joystick
#define JOY_FLIP_X false
#define JOY_FLIP_Y false
#define JOYSTICK_DEADZONE 10 //deadzone in the joystick to prevent drift (in percent)

#define NO_THUMB false //If for some reason you don't want to track the thumb

#define USING_CALIB_PIN true //When PIN_CALIB is shorted (or it's button pushed) it will reset calibration if this is on.

#define USING_FORCE_FEEDBACK true //Force feedback haptics allow you to feel the solid objects you hold
#define FLIP_FORCE_FEEDBACK true
#define SERVO_SCALING false //dynamic scaling of servo motors

#if defined(ESP32)
  //(This configuration is for ESP32 DOIT V1 so make sure to change if you're on another board)
  //To use a pin on a multiplexer, use MUX(pin). So for example pin 15 on a mux would be MUX(15).
  #define PIN_PINKY     32//These 5 are for flexion
  #define PIN_RING      35
  #define PIN_MIDDLE    34
  #define PIN_INDEX     39
  #define PIN_THUMB     36
  #define PIN_JOY_X     33
  #define PIN_JOY_Y     25
  #define PIN_JOY_BTN   26
  #define PIN_A_BTN     27 
  #define PIN_B_BTN     14
  #define PIN_TRIG_BTN  12 //unused if gesture set
  #define PIN_GRAB_BTN  13 //unused if gesture set
  #define PIN_PNCH_BTN  23 //unused if gesture set
  #define PIN_CALIB     15 //button for recalibration (You can set this to GPIO0 to use the BOOT button, but only when using Bluetooth.)
  #define DEBUG_LED 2
  #define PIN_PINKY_MOTOR     19  //used for force feedback
  #define PIN_RING_MOTOR      18 //^
  #define PIN_MIDDLE_MOTOR    5 //^
  #define PIN_INDEX_MOTOR     17 //^
  #define PIN_THUMB_MOTOR     16 //^
  #define PIN_MENU_BTN        34

  //Splay pins. Only used for splay tracking gloves. Use MUX(pin) if you are using a multiplexer for it.
  #define PIN_PINKY_SPLAY  MUX(14)
  #define PIN_RING_SPLAY   MUX(11)
  #define PIN_MIDDLE_SPLAY MUX(8)
  #define PIN_INDEX_SPLAY  MUX(5)
  #define PIN_THUMB_SPLAY  MUX(2)
  

  //Select pins for multiplexers, set as needed if using a mux. You can add or remove pins as needed depending on how many select pins your mux needs.
  #define PINS_MUX_SELECT     27,  /*S0 pin*/ \
                              14,  /*S1 pin*/ \
                              12,  /*S2 pin*/ \
                              13   /*S3 pin (if your mux is 3-bit like 74HC4051 then you can remove this line and the backslash before it.)*/
  
  #define MUX_INPUT 35  //the input or SIG pin of the multiplexer. This can't be a mux pin.

  //Signal mixing for finger values. Options are: MIXING_NONE, MIXING_SINCOS
  //For double rotary hall effect sensors use MIXING_SINCOS. For potentiometers use MIXING_NONE.
  #define FLEXION_MIXING MIXING_NONE
    //Secondary analog pins for mixing flexion values. Only used by MIXING_SINCOS. Use MUX(pin) if you are using a multiplexer for it.
    #define PIN_PINKY_SECOND     MUX(13) 
    #define PIN_RING_SECOND      MUX(10)
    #define PIN_MIDDLE_SECOND    MUX(7)
    #define PIN_INDEX_SECOND     MUX(4)
    #define PIN_THUMB_SECOND     MUX(1)
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

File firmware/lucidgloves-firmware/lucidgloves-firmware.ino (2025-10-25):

/*
 * LucidGloves Firmware Version 4
 * Author: Lucas_VRTech - LucidVR
 * lucidvrtech.com
 */


#include "src/Main.h"

/*
 * 
 *  THE CONFIG SETTINGS ARE NO LONGER STORED HERE. THEY HAVE BEEN MOVED TO Config.h
 *  
 *  You can now change the settings over at config.h before uploading to your gloves.
 * 
 */


Main mainClass;

void setup(){
  mainClass.setup();
}

void loop(){
  mainClass.loop();
}

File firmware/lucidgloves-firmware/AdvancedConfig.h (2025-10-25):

#pragma once
#include "src/Util/ConfigUtils.h"
//THIS FILE HAS SOME EXTRA SETTINGS, MAIN SETTINGS ARE IN Config.h

#define LOOP_TIME 1 //How much time between data sends (ms), set to 0 for a good time :)
#define CALIBRATION_LOOPS -1//How many loops should be calibrated. Set to -1 to always be calibrated.

//Encoding
#define ENCODING ENCODE_ALPHA

#define NUM_FINGERS 5

//Bluetooth advaned settings
#define BT_ECHO false//Should the bluetooth data be echoed over serial for debugging

//ESP32 Specific Settings
#define ESP32_DUAL_CORE false //Should inputs be handled on a separate core for communication for more accurate rotation counting

//Finger indeces (not used for legacy)
#define PINKY_IND 4
#define RING_IND 3
#define MIDDLE_IND 2
#define INDEX_IND 1
#define THUMB_IND 0

//Automatically set ANALOG_MAX depending on the microcontroller
#if defined(__AVR__)
#define ANALOG_MAX 1023
#elif defined(ESP32)
#define ANALOG_MAX 4095 
#endif


#define MULTIPLEXER_DELAY   5 //How many microseconds should be delayed between multiplexer reads


//ANALOG_MAX OVERRIDE:
//#define ANALOG_MAX 4095 //uncomment and set as needed

#ifndef ANALOG_MAX
#error "This board doesn't have an auto ANALOG_MAX assignment, please set it manually by uncommenting the line below ANALOG_MAX OVERRIDE in AdvancedConfig.h"
#endif

//Filtering and clamping analog inputs
#define CLAMP_ANALOG_MAP true //clamp the mapped analog values from 0 to ANALOG_MAX

// Enable and set min and max to match your sensor's expected raw value range
// This discards any spurious values outside of the useful range
#define CLAMP_SENSORS false  //clamp the raw sensor values
#define CLAMP_MIN 0  //the minimum value from the flexion sensors
#define CLAMP_MAX ANALOG_MAX  //the maximum value from the flexion sensors

// You must install RunningMedian library to use this feature
// https://www.arduino.cc/reference/en/libraries/runningmedian/
#define ENABLE_MEDIAN_FILTER false //use the median of the previous values, helps reduce noise
#define MEDIAN_SAMPLES 10

//intermediate filtering. Options are INTERFILTER_NONE, INTERFILTER_LIMITS (filter is only used for limit calib), INTERFILTER_ALL (filter all the way)
#define INTERFILTER_MODE INTERFILTER_LIMITS
#define INTERFILTER_SAMPLES 10

//ESP dual core hardware check
#if defined(ESP32) && ESP32_DUAL_CORE
  #define ESP32_DUAL_CORE_SET true
#endif

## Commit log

2021-04-20 New firmware
    [Prot3.1_EasySpool.STL, Prot3.1_EasySpool_Thicker.STL, Prot3.1_GuideNode.STL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]
2021-04-25 Always calibrating by default
2021-04-25 Fix finger indices for legacy encoding
2021-05-02 Add different pin configurations for Arduino/ESP32 (Suggested by Jakub Nagy)
2021-05-02 Added calibration reset pullup
    [lucidgloves-firmware.ino]
2021-05-02 Hot-calibration pin working with driver
2021-05-03 Fix joystick x axis
    [lucidgloves-firmware.ino]
2021-05-10 Added 3.1R2 spool
    [Prot3.1R2_EasySpool.STL, Prot3.1R2_SpoolCover.STL, Prot3.1R2_SpoolCover_Taller.STL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]
2021-05-16 Using calibration pin set to false by default
2021-06-20 Add servo haptics with static scaling
2021-07-03 Add calibration button send
2021-07-03 Fix servo motor direction for proto 4
2021-08-02 Add menu button
2021-08-07 Add Prototype 4 hardware
    [GreenPotSlideHolder.STL, HapticSpool.STL, Quest2_MountSlider.STL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]
2021-08-07 Switch to Alpha encoding
2021-08-08 Add tensioners to prototype 4 for both pot types
    [Tensioner_GreenPot.STL, Tensioner_WLPot.STL]
2021-08-15 Add finger indeces to advanced config
2021-08-15 Gestures now use finger indeces
2021-08-29 Added ESP32 Package Installation Documentation
2021-09-22 Added a green potentiometer elastic holder
    [GreenPotElasticHolder.stl]
2021-09-23 Added a green potentiometer elastic holder again
    [GreenPotElasticHolder.stl]
2021-09-27 Added green pot elastic holder
    [GreenPotElasticHolder.stl]
2021-09-27 Added green potentiometer elastic holder
    [GreenPotElasticHolder.stl]
2021-09-29 Adds button invert and auto ANALOG_MAX assignment
    [AdvancedConfig.h, lucidgloves-firmware.ino]
2021-10-03 Median filtering, and analog value clamping
2021-10-29 Add reinforced version of servo holder
    [GreenHapticMountHolder_v2.5.STL]
2021-11-16 Add new prototype 4.1 hardware
    [GreenPotElasticHolder_Proto4.1.STL, GreenPotSildeHolder_Proto4.1.STL, HapticSpool_Proto4.1.STL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]
2022-03-15 Add rigid mount for both hands
    [RigidMount_leftHand.STL, RigidMount_rightHand.STL]
2022-03-22 Add new guide nodes for proto 4.1
    [GuideNode_upgraded.STL]
2022-04-25 fixes the right hand stl (#71)
    [RigidMount_rightHand.STL]
2022-07-12 endcap from proto 3 (#78)
    use sf = 100 * width / 14.5 for scaling
    [Prot4_EndCap.STL]
2022-07-12 Correcting numbers and formatting in README.md (#67)
    * Corrected numbers and formatting in README.md
    The 3d printed parts list needed for each hand, was actually for both hands in some cases.
    A few other formatting inconsistencies.
    * README.md formatting and grammar
    * More README formatting fixes
2022-07-12 Fix Readme Formatting (#75)
    The bullets weren’t formatted right
2022-07-19 ESP32 before AVR, because more people use ESP32's than Arduinos now
2022-07-19 Add ESP32 mount for JST's
    [ESP32_Wroom_Holder_Desoldered_JST.STL]
2022-07-30 Error out if users try to use gpio0 while using usb communication. NO BUGS ALLOWED!!!
    [lucidgloves-firmware.ino]
2022-08-11 Bugfix/fix link to parts guides (#80)
    * Fix link for chinese readme
    * Fix link to printing guides
2022-08-11 Fixed prototype 4 tutorial, printing guide link (#83)
2022-08-14 Fix calibration for sin-cos
2022-12-08 Debug timers
2022-12-08 Make finger pos a void function
2022-12-08 Make mux into switch statement
2022-12-08 Fix comms lag caused by mutex order
    [ConfigUtils.h]
2022-12-08 Add support for intermediate mixing, for more accurate calibration limits.
2022-12-08 Debug printouts
2022-12-08 Fix totalOffset corruption bug
    [AdvancedConfig.h]
2022-12-08 Fix limits on reset for proto5
    [AdvancedConfig.h]
2022-12-09 Add prototype 5 BETA STL's
    [BearingRetainer_v1.2.STL, EndRing_v1.2_13mm.STL, EndRing_v1.2_15mm.STL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]
2022-12-10 Update sensorHousing version from 4.1 to 5.9
    [SensorHousing_v4.1.STL, SensorHousing_v5.9.STL]
2022-12-14 Update magnetPinion to v5.2
    [MagnetPinion_v4.0.STL, MagnetPinion_v5.2.STL]
2022-12-14 Update to MagnetPinion_v5.3
    [MagnetPinion_v5.2.STL, MagnetPinion_v5.3.STL]
2023-02-18 Fix from danwillm - vibration code from OpenGloves retracting servos
2023-07-18 Remove debug printouts for input.ino
2025-09-27 Fix encode macro typo
    [AdvancedConfig.h]
2025-09-27 Fix proto 4 compatibility
    [Config.h, InputManager.cpp, Main.cpp]
2025-09-27 Fix non dual code bug
    [AdvancedConfig.h, Main.cpp]
2025-10-25 fix: re-add local fixes after resync
    [Config.h, ConfigUtils.h, Main.cpp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]
2025-10-27 fix: resolve requested changes from @lucas-vrtech
    [Config.h, Main.cpp]
2025-10-27 fix: include guards for ConfigUtils.h
    Fixes 'redefinition of ordered_lock' error, which happens because of multiple different relative inputs, leading to #pragma once not working
    [ConfigUtils.h]
